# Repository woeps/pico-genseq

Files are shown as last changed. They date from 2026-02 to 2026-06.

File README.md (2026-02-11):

# GenSeq

A generative hardware MIDI sequencer based on the Raspberry Pi Pico (RP2040).

:warning: This project is still in development. It may take some (more) time to get to a stable state. :warning:

## Goal

GenSeq is a hardware MIDI sequencer that creates generative musical patterns based on separate sequences of pitches and rhythms. It provides real-time MIDI output with precise timing, an intuitive user interface, and extensible architecture for future enhancements.

## Key Features

- **Dual-core architecture** - Separates UI and sequencer logic for responsive performance
- **Generative sequencing** - Creates patterns using Euclidean rhythm algorithms
- **Real-time MIDI output** - Precise timing with MIDI clock support
- **Interactive UI** - LCD display, rotary encoder, and button matrix
- **Pattern management** - Multiple patterns with shared pitch/rhythm sets
- **Extensible design** - Clean architecture for easy feature additions

## Documentation

Online documentation is available at [https://woeps.github.io/pico-genseq/](https://woeps.github.io/pico-genseq/).

For comprehensive documentation, see the [docs/](docs/) directory:
- [Architecture Deep Dive](docs/architecture/architecture-deep-dive.md) - Technical details
- [Build & Flash Guide](docs/technical/build-flash.md) - Detailed instructions
- [Dependencies & Setup](docs/reference/dependencies.md) - Development environment
- [Troubleshooting](docs/reference/troubleshooting.md) - Common issues

## Building
- `mkdir build`
- `cd ./build`
- `cmake .. -G Ninja`
- `ninja clean` - optionally
- `ninja`

## Flashing
- either: copy `build/genseq.uf2` to the device
- or: use debugger ([PicoProbe](docs/technical/build-flash.md#method-2-picoprobe-flashing-advanced))

## Debugging
- in VSCode, press F5 / select `Pico Debug (Cortex-Debug)` in Run & Debug Toolbar

## Resources

- Midi Clock (tempo) analyzer: https://disasterarea.io/midiclock

## TODO

See [TODO.md](TODO.md) for detailed task list and implementation notes.

Key upcoming features:
- [ ] Manual step editing for rhythm sets
- [ ] UI configuration for settings (Euclidean pulses, length, etc.)
- [ ] Decouple MIDI from sequencer core
- [ ] Move step selection logic to play_mode.cpp

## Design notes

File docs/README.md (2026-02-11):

# GenSeq Documentation

Welcome to the GenSeq documentation. This section provides comprehensive guides for developing, building, and understanding the GenSeq MIDI sequencer project.

## Quick Start

- [Repository Structure](architecture/repository-structure.md) - Understand the project organization
- [Dependencies & Requirements](reference/dependencies.md) - Set up your development environment
- [Build & Flash](technical/build-flash.md) - Build and flash the firmware

## Core Documentation

### Architecture
- [Repository Structure](architecture/repository-structure.md) - Project layout and dual-core architecture
- [Architecture Deep Dive](architecture/architecture-deep-dive.md) - Technical details of the system design
- [Hardware Configuration](architecture/hardware-config.md) - Pin assignments and wiring diagrams

### Development
- [CMake Configuration](development/cmake-configuration.md) - Build system setup and common operations
- [Development Workflow](development/development-workflow.md) - Coding standards and best practices
- [UI System Guide](development/ui-system-guide.md) - User interface architecture and components

### Technical
- [MIDI Implementation](technical/midi-implementation.md) - MIDI output and timing details
- [Build & Flash Guide](technical/build-flash.md) - Build instructions and flashing procedures

### Reference
- [Dependencies & Requirements](reference/dependencies.md) - Software and hardware requirements
- [Troubleshooting FAQ](reference/troubleshooting.md) - Common issues and solutions

## Project Overview

GenSeq is a generative hardware MIDI sequencer based on the Raspberry Pi Pico (RP2040). It features:

- **Dual-core architecture** separating UI and sequencing
- **Real-time MIDI output** with precise timing
- **Generative patterns** using Euclidean rhythms
- **Extensible UI** with LCD display and LED matrix
- **Full MIDI implementation** including clock output

## Getting Started

1. **Set up environment** - Follow [Dependencies & Requirements](reference/dependencies.md)
2. **Build the project** - Use the [Build & Flash Guide](technical/build-flash.md)
3. **Understand the architecture** - Read [Repository Structure](architecture/repository-structure.md)
4. **Start developing** - Follow the [Development Workflow](development/development-workflow.md)

## Documentation Structure

```
docs/
├── README.md                    # This file
├── architecture/                # Architecture documentation
│   ├── repository-structure.md  # Project organization
│   ├── architecture-deep-dive.md # Technical architecture
│   └── hardware-config.md       # Hardware documentation
├── development/                 # Development guides
│   ├── cmake-configuration.md   # Build system details
│   ├── development-workflow.md  # Development guide
│   └── ui-system-guide.md       # UI architecture
├── technical/                   # Technical documentation
│   ├── build-flash.md          # Build and flash procedures
│   └── midi-implementation.md   # MIDI system details
└── reference/                   # Reference materials
    ├── dependencies.md          # Setup requirements
    └── troubleshooting.md      # Common issues
```

## Contributing to Documentation

When adding new features:
1. Update relevant documentation sections
2. Add new pages for major features
3. Update pin assignments in [Hardware Configuration](architecture/hardware-config.md)
4. Document new commands in [Architecture Deep Dive](architecture/architecture-deep-dive.md)

## Resources

- [Main Project README](../README.md)
- [Pico SDK Documentation](https://raspberrypi.github.io/pico-sdk-doxygen/)
- [RP2040 Datasheet](https://datasheets.raspberrypi.org/rp2040/rp2040-datasheet.pdf)
- [MIDI Specification](https://www.midi.org/specifications)

## Support

If you encounter issues:
1. Check the [Troubleshooting FAQ](reference/troubleshooting.md)
2. Search existing GitHub issues
3. Create a new issue with detailed information
4. Include debug output and hardware details

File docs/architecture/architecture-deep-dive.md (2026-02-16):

# Architecture Deep Dive

## Overview

The GenSeq architecture leverages the RP2040's dual-core design to create a responsive real-time MIDI sequencer. This deep dive explores the technical decisions, data structures, and communication patterns that make it possible.

## Dual-Core Architecture

### Core Responsibilities

```
┌─────────────────┐    Commands     ┌─────────────────┐
│   Core 0        │ ──────────────► │   Core 1        │
│                 │                 │                 │
│ • UI Input      │                 │ • Sequencing    │
│ • Display       │                 │ • MIDI Output   │
│ • LEDs          │                 │ • Timing        │
│ • User Logic    │                 │ • Pattern Mgmt  │
│                 │                 │                 │
└─────────────────┘                 └─────────────────┘
```

### Why Dual-Core?

1. **Real-time Constraints**: MIDI timing must be precise (±1ms)
2. **UI Responsiveness**: User interactions should never affect timing
3. **Separation of Concerns**: Clean architecture boundaries
4. **Future Expansion**: Room for additional features

### Core Synchronization

The cores communicate through:
- **Mailbox**: Fast inter-core messaging
- **Command Queue**: Asynchronous command processing
- **Shared Memory**: Read-only data structures

## Data Architecture

### Musical Data Separation

The sequencer separates musical data into three distinct types:

```
Pattern
├── Pitch Set      (What notes to play)
├── Rhythm Set     (When to play them)
└── Play Mode      (How to play them)
```

#### Pitch Set
```cpp
class PitchSet {
    std::vector<uint8_t> pitches;    // MIDI note numbers
    std::vector<uint8_t> velocities; // Note velocities
    bool active;                     // Enable/disable
};
```

- Contains note information (C4, G4, etc.)
- Independent of timing
- Can be reused across patterns

#### Rhythm Set (Gate Set)
```cpp
class GateSet {
    std::vector<bool> gates;         // On/off for each step
    std::vector<uint8_t> lengths;    // Gate length percentage
    uint8_t length;                  // Number of steps
    bool active;                     // Enable/disable
};
```

- Defines timing and rhythm
- Euclidean algorithm for generation
- Gate length controls note duration

#### Pattern
```cpp
class Pattern {
    PitchSet* pitchSet;              // Reference to pitch data
    GateSet* gateSet;                // Reference to rhythm data
    PlayMode playMode;               // Playback algorithm
    uint8_t currentStep;             // Current position
    bool active;                     // Play this pattern?
};
```

- Combines pitch and rhythm sets
- Multiple patterns can share sets
- Each pattern has independent state

### Play Modes

Different algorithms for note selection:

1. **Forward**: Linear progression through steps
2. **Random**: Random note selection
3. **Euclidean**: Evenly spaced notes
4. **Reverse**: Backward progression

## Command System

### Command Structure

```cpp
enum class CommandType {
    PLAY,
    STOP,
    SET_BPM,
    SET_PATTERN_ACTIVE,
    MODIFY_PITCH_SET,
    MODIFY_GATE_SET,
    // ... more commands
};

struct Command {
    CommandType type;
    uint8_t data[4];  // Command-specific data
};
```

### Command Flow

```
UI Core (Core 0)              Sequencer Core (Core 1)
     │                              │
     ├─> User presses PLAY ─────────► │
     │                              │
     ├─> Create Command             │
     │    type = PLAY               │
     │                              │
     ├─> Send via Mailbox ──────────►│
     │                              │
     │                         Process Command
     │                              │
     │                         Start Sequencer
     │                              │
     │                         Send MIDI Clock
```

### Command Processing

The sequencer processes commands in its main loop:
```cpp
void sequencerLoop() {
    while (true) {
        // Check for commands
        if (multicore_fifo_rvalid()) {
            Command cmd = multicore_fifo_pop_blocking();
            processCommand(cmd);
        }
        
        // Update sequencing
        if (shouldTick()) {
            processTick();
        }
        
        // Send MIDI
        sendPendingMIDI();
    }
}
```

## Timing System

### Tick-Based Sequencing

The sequencer uses a tick-based timing system:

- **PPQN**: Pulses Per Quarter Note (typically 24)
- **BPM**: Beats Per Minute (user configurable)
- **Tick Interval**: 60,000,000 / (BPM * PPQN * 1000) microseconds

### Timing Precision

```cpp
// Timer interrupt for precise timing
void timerCallback() {
    sequencerTick();
    clearAlarm();
    setAlarm(nextTickTime);
}
```

### MIDI Clock Generation

MIDI clock messages are sent at 24 PPQN:
```cpp
void sendMIDIClock() {
    sendMIDIMessage(0xF8); // MIDI Clock message
}
```

## UI Architecture

### Component Hierarchy

```
UIController
├── hardware/                (concrete types, no interfaces)
│   ├── HardwareConfig
│   ├── Button (×6, A-F)
│   ├── Encoder
│   ├── Led
│   └── LedMatrix
├── state/                   (state management)
│   ├── StateManager (singleton)
│   ├── Reducer (pure function + state-setters)
│   └── UIState
└── views/                   (render-only)
    └── MainView
```

### Data Flow

```
Button/Encoder → Event → StateManager → reduce(state, event) → new state → listener → View::render()
                                                                    ↓
                                                              commands::sendCommand() → Core 1
```

### Reducer Pattern

State transitions are handled by a pure reducer function. State-setter functions abstract away
mutating state fields and sending the corresponding commands:

```cpp
// State-setter functions: mutate state and send the corresponding command
void setBpm(UIState& state, int bpm);
void setPlaying(UIState& state, bool playing);

// All state logic in one place
UIState reduce(const UIState& state, const Event& event) {
    UIState newState = state;
    switch (event.type) {
        case EventType::ENCODER_CHANGED:
            setBpm(newState, state.bpm + event.data.encoder.delta);
            break;
        case EventType::BUTTON_PRESSED:
            setPlaying(newState, !state.playing);
            break;
    }
    return newState;
}
```

### View System

Views are render-only — they never mutate state:

```cpp
class IView {
public:
    virtual ~IView() = default;
    virtual void onEnter() {}
    virtual void onExit() {}
    virtual void render(const UIState& state) = 0;
};
```

## Memory Management

### Core-Specific Memory

Each core has its own stack:
```cpp
// Core 0 stack (UI)
#define UI_STACK_SIZE 0x1000

// Core 1 stack (Sequencer)
#define SEQUENCER_STACK_SIZE 0x2000
```

### Shared Memory

Read-only data can be shared:
```cpp
// Flash-stored data accessible by both cores
const uint8_t* sharedData = (const uint8_t*)0x10000000;
```

### Dynamic Allocation

Minimal dynamic allocation to avoid fragmentation:
- Pre-allocated buffers
- Fixed-size arrays
- Pool allocators for frequent allocations

## Interrupt Handling

### Core 0 Interrupts

- **GPIO**: Button and encoder inputs
- **I2C**: Display communication
- **Timer**: UI refresh timing

### Core 1 Interrupts

- **Timer**: Sequencer tick
- **UART**: MIDI transmission
- **DMA**: Efficient data transfer

### PIO Programs

Custom PIO programs for hardware:

```pio
// Encoder reading PIO
program encoder_reader {
    set pins, 0
    set x, 0
    
    label loop:
    in pins, 2
    mov x, isr
    jmp x != y, changed
    jmp loop
    
    label changed:
    mov y, x
    irq 0
    jmp loop
}
```

## Performance Considerations

### Critical Sections

MIDI output must be uninterrupted:
```cpp
// Disable interrupts during critical MIDI operations
uint32_t interrupt_state = save_and_disable_interrupts();
sendMIDIMessage(msg);
restore_interrupts(interrupt_state);
```

### DMA Usage

DMA for efficient data transfer:
```cpp
// DMA for LED matrix updates
dma_channel_configure(dma_chan,
    &dma_config,
    &led_data,          // Destination
    &led_buffer,        // Source
    LED_COUNT,          // Transfer count
    true                // Start immediately
);
```

### Optimization Strategies

1. **Minimize Inter-Core Communication**: Batch commands
2. **Use Lookup Tables**: For common calculations
3. **Avoid Floating Point**: Use fixed-point arithmetic
4. **Cache Frequently Used Data**: Keep in fast memory

## Debugging Architecture

### Core-Specific Debugging

Each core can be debugged independently:
```bash
# Debug Core 0 (UI)
openocd -f interface/cmsis-dap.cfg -f target/rp2040.cfg -c "bp main.0"

# Debug Core 1 (Sequencer)
openocd -f interface/cmsis-dap.cfg -f target/rp2040.cfg -c "bp main.1"
```

### Logging

Different logging levels for each core:
```cpp
// UI logging
printf("UI: Button pressed %d\n", buttonId);

// Sequencer logging
printf("SEQ: Pattern %d tick %d\n", patternId, tick);
```

## Future Architecture Considerations

### Scalability

The architecture supports:
- Additional patterns
- New play modes
- More UI views
- Extra hardware components

### Extensibility

Adding new features:
1. UI features: Add to Core 0
2. Sequencer features: Add to Core 1
3. New commands: Extend command enum
4. New hardware: Add to HAL

### Performance Headroom

Current utilization:
- Core 0: ~30% (UI is lightweight)
- Core 1: ~60% (Sequencing is intensive)
- Memory: ~50% of RAM available

## Summary

The GenSeq architecture successfully separates UI and sequencing concerns across two cores, enabling real-time MIDI performance while maintaining responsive user interaction. The clean data architecture and command system provide a solid foundation for future enhancements.

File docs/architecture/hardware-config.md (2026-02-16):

# Hardware Configuration

## Overview

The GenSeq hardware configuration defines all pin assignments, supported components, and wiring diagrams. This guide covers everything needed to connect the hardware components correctly.

## Pin Assignments

### Current Pin Configuration

```cpp
// From src/config/pins.h

// BUTTONS (A-F)
#define BUTTON_A_PIN 20
#define BUTTON_B_PIN 21
#define BUTTON_C_PIN 0  // TODO: assign actual pin
#define BUTTON_D_PIN 0  // TODO: assign actual pin
#define BUTTON_E_PIN 0  // TODO: assign actual pin
#define BUTTON_F_PIN 0  // TODO: assign actual pin

// ENCODER
#define ENCODER_PIN_A 14  // Encoder phase A
#define ENCODER_PIN_B 15  // Encoder phase B
#define ENCODER_PIO pio0  // PIO block 0
#define ENCODER_SM 0      // State machine 0

// MIDI UART
#define MIDI_UART uart1       // UART block 1
#define MIDI_UART_PIN_TX 8    // MIDI transmit pin
#define MIDI_UART_PIN_RX 9    // MIDI receive pin

// POTENTIOMETER (ADC)
#define POT_PIN 26            // 10kΩ linear pot on ADC0

// STATUS LED
#define LED_PIN 25            // Onboard LED
```

### Pin Map Diagram

```
Raspberry Pi Pico Pinout
========================

          3V3  (40) [ ] (39)  GND
          GPIO2 (35) [ ] (38)  GPIO3
          GPIO4 (34) [ ] (37)  GPIO5  ← I2C SCL (Display)
          GPIO6 (33) [ ] (36)  GPIO7
          GPIO8 (32) [ ] (31)  GPIO9  ← MIDI RX
  MIDI TX → GPIO10(31) [ ] (30)  GPIO11
          GPIO12(30) [ ] (29)  GPIO13
 Encoder A → GPIO14(29) [ ] (28)  GPIO13 ← Encoder B
          GPIO16(27) [ ] (27)  GPIO17
          GPIO18(26) [ ] (26)  GPIO19
Button E → GPIO20(25) [ ] (25)  GPIO21 ← Button A
          GPIO22(24) [ ] (24)  GPIO23
          GND   (23) [ ] (23)  VSYS
          VBUS  (22) [ ] (22)  GND
          3V3   (21) [ ] (21)  3V3
          LED   (20) [ ] (20)  GND
```

## Hardware Components

### 1. LCD Display

**Specification**: HD44780 with FC113 I2C controller

**Connection**:
```
Pico      →  Display Module
GPIO4     →  SDA
GPIO5     →  SCL
3V3       →  VCC
GND       →  GND
```

**I2C Address**: 0x27 (configurable via jumpers)

**Library**: Custom driver in `src/ui/hardware/driver/LCD_I2C.cpp`

### 2. Rotary Encoder

**Specification**: Quadrature encoder with push button

**Connection**:
```
Pico      →  Encoder
GPIO14    →  Phase A
GPIO15    →  Phase B
GPIO20    →  Button
3V3       →  VCC
GND       →  GND
```

**Implementation**: PIO-based for interrupt-free reading

### 3. MIDI Interface

**Specification**: 5-pin DIN MIDI connector

**Circuit**:
```
Pico TX → 220Ω → MIDI Pin 5
MIDI Pin 4 → 220Ω → Pico RX
MIDI Pin 2 → GND
```

**Isolation**: Opto-isolator recommended for MIDI input

### 4. Button Matrix

**Specification**: 16 buttons in 8x2 matrix

**Connection Pattern**:
```
Rows: GPIO22, GPIO21, GPIO20, GPIO19
Cols: GPIO18, GPIO17, GPIO16, GPIO15
```

**Scanning**: Row-by-row scanning with debouncing

### 5. Potentiometer

**Specification**: 10kΩ linear potentiometer

**Connection**:
```
Pico      →  Potentiometer
GPIO26    →  Wiper (middle pin) via RC low-pass filter
3V3       →  One outer pin
GND       →  Other outer pin
```

**RC Low-Pass Filter**:
```
POT_WIPER ─── 1kΩ ─── GPIO26 (ADC0)
                  │
                100nF
                  │
                 GND
```
- **R**: 1kΩ, **C**: 100nF (cutoff ≈ 1.6 kHz)
- Filters high-frequency noise while preserving responsiveness for manual control

**ADC**: 12-bit (0–4095), read via `hardware_adc`

**Noise Filtering**: RC low-pass filter on input + EMA software smoothing (α=1/4) + threshold-based change detection (±4 LSBs)

### 6. LED Matrix

**Specification**: 16x2 WS2812B LED strip

**Connection**:
```
Pico GPIO23 → LED Data In
5V          → LED VCC
GND         → LED GND
```

**Driver**: DMA-based for smooth updates

## Wiring Diagram

### Complete Wiring

```
┌─────────────────────────────────────────────────────┐
│                   PICO BOARD                        │
│                                                     │
│    [USB]                                           │
│                                                     │
│  GPIO4 ────────┐                                   │
│  GPIO5 ────────┼───[ I2C LCD ]                     │
│  3V3 ─────────┘                                   │
│  GND ─────────────────────────────────────────────┐ │
│                                                   │ │
│  GPIO14 ──────┐                                   │ │
│  GPIO15 ──────┼───[ ENCODER ]                     │ │
│  GPIO20 ──────┘                                   │ │
│                                                   │ │
│  GPIO8 ───┐                                        │ │
│  GPIO9 ───┼───[ MIDI CIRCUIT ]                     │ │
│  GND ─────┘                                        │ │
│                                                   │ │
│  GPIO23 ─────────[ LED STRIP ]────────────────────┘ │
│                                                     │
│  [OTHER GPIO] ────[ BUTTON MATRIX ]                │
│                                                     │
└─────────────────────────────────────────────────────┘
```

## Adding New Hardware

### 1. Define Pins

Add to `src/config/pins.h`:
```cpp
// New hardware pins
#define NEW_DEVICE_PIN 26
#define NEW_DEVICE_IRQ_PIN 27
```

### 2. Create Driver

Create files in `src/ui/hardware/driver/`:
```cpp
// new_device.h
class NewDevice {
public:
    NewDevice(uint8_t pin);
    void init();
    void update();
    int read();
private:
    uint8_t _pin;
};
```

### 3. Update CMakeLists.txt

Add to CMakeLists.txt if needed:
```cmake
target_link_libraries(genseq
    # ... existing libraries ...
    hardware_spi  # If using SPI
)
```

### 4. Integrate with UI

Add to UI controller:
```cpp
// In ui.cpp
NewDevice newDevice(NEW_DEVICE_PIN);

void updateUI() {
    newDevice.update();
    // ... other updates
}
```

## PIO Programs

### Encoder Reader PIO

Located at `src/ui/hardware/driver/encoder.pio`:

```pio
.program encoder_reader
.side_set 1 opt

; Read encoder state change
loop:
    in pins, 2        ; Read both encoder pins
    mov x, isr        ; Save to X
    jmp x != y, changed ; Check if changed
    jmp loop          ; No change, continue
    
changed:
    mov y, x          ; Save new state
    irq 0             ; Signal change
    jmp loop          ; Continue
```

### WS2812 LED PIO

Generated from `src/ui/hardware/driver/ws2812.pio`:
- Handles timing-critical LED data
- Uses DMA for efficient transfers
- Supports RGB color format

## Hardware Abstraction Layer

### Interfaces

All hardware implements standard interfaces:

```cpp
// Input devices
class IInput {
public:
    virtual void update() = 0;
    virtual bool hasChanged() = 0;
    virtual int getValue() = 0;
};

// Output devices
class IOutput {
public:
    virtual void update() = 0;
    virtual void setValue(int value) = 0;
};
```

### Hardware Configuration

Configuration in `src/ui/hardware/driver/HardwareConfig.h`:
```cpp
struct HardwareConfig {
    // Display settings
    static const uint8_t DISPLAY_WIDTH = 16;
    static const uint8_t DISPLAY_HEIGHT = 2;
    
    // LED settings
    static const uint16_t LED_COUNT = 32;
    static const uint8_t LED_BRIGHTNESS = 128;
    
    // Debounce settings
    static const uint8_t DEBOUNCE_MS = 50;
};
```

## Power Considerations

### Power Requirements

- **Pico Board**: 40mA @ 5V
- **LCD Display**: 20mA @ 5V
- **LED Strip**: 60mA per LED @ 5V (full brightness white)
- **MIDI Interface**: 5mA @ 5V
- **Total**: ~2A @ 5V with all LEDs at full brightness

### Power Supply Recommendations

1. **USB Power**: Sufficient for development (500mA)
2. **External Supply**: Required for full LED usage
3. **Decoupling**: 100µF capacitor near LED strip
4. **Protection**: 500mA polyfuse on 5V line

## Signal Integrity

### I2C Considerations

- Pull-up resistors: 4.7kΩ on SDA/SCL
- Cable length: < 1m recommended
- Speed: 100kHz (standard mode)

### MIDI Considerations

- Isolation: Opto-isolator on input
- Termination: Not required for short cables
- Cable length: Up to 15m with proper shielding

### GPIO Considerations

- 3.3V logic levels
- Input protection: Series resistors for external signals
- Output current: Max 16mA per pin

### ADC Considerations

- RC low-pass filter (1kΩ + 100nF) on potentiometer input to reduce high-frequency noise
- Cutoff frequency: ~1.6 kHz
- Source impedance kept below RP2040 recommended maximum (~100kΩ)

## Troubleshooting Hardware

### Common Issues

1. **Display not working**:
   - Check I2C address (use I2C scanner)
   - Verify pull-up resistors
   - Check wiring connections

2. **Encoder jitter**:
   - Add hardware debouncing (0.1µF capacitor)
   - Increase software debounce time
   - Check for noise sources

3. **MIDI not sending**:
   - Verify MIDI wiring
   - Check baud rate (31250)
   - Test with MIDI monitor

4. **LED flickering**:
   - Check power supply
   - Verify ground connection
   - Reduce brightness

### Testing Procedures

1. **Continuity Test**: Verify all connections
2. **Voltage Test**: Check power at each component
3. **Signal Test**: Use logic analyzer for timing
4. **Isolation Test**: Test components individually

## Future Hardware Expansion

### Planned Additions

1. **Storage**: SD card for pattern storage
2. **Connectivity**: USB MIDI host mode
3. **Expansion**: More buttons and LEDs
4. **Sensors**: CV inputs for modulation

### Pin Availability

Free pins for expansion:
- GPIO26, GPIO27, GPIO28, GPIO29
- ADC pins available for analog input

## Summary

The hardware configuration is designed for:
- Clean signal routing
- Proper power distribution
- Easy expansion
- Reliable operation

All pin assignments are documented and easily modifiable in the source code. The hardware abstraction layer makes it simple to add new components or modify existing ones.

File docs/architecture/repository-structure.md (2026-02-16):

# Repository Structure

## Overview

The GenSeq project follows a well-organized structure that separates concerns between the user interface and sequencer logic, leveraging the dual-core architecture of the Raspberry Pi Pico (RP2040).

```
genseq/
├── src/                    # All source code
│   ├── sequencer/         # Core sequencing logic (runs on core 1)
│   ├── ui/                # User interface components (runs on core 0)
│   ├── commands/          # Inter-core communication
│   ├── config/            # Pin assignments & hardware config
│   ├── generated/         # Auto-generated PIO headers
│   └── genseq.cpp         # Main entry point
├── docs/                  # Documentation
├── build/                 # Build output directory
├── case/                  # Hardware case designs
├── data/                  # Datasheet & Spec files
├── .vscode/               # VSCode configuration
├── .clangd                # clangd configuration
├── CMakeLists.txt         # CMake build configuration
├── pico_sdk_import.cmake  # Pico SDK import
└── README.md              # Project overview
```

## Architecture Philosophy

### Dual-Core Separation

The project strategically uses both cores of the RP2040:

- **Core 0**: User Interface (UI)
  - Handles all user input (buttons, encoders)
  - Manages display updates
  - Sends commands to sequencer
  - Responsive to user interactions
  
- **Core 1**: Sequencer Logic
  - Real-time MIDI sequencing
  - Pattern management
  - Timing-critical operations
  - Uninterrupted MIDI output

### Benefits of This Architecture

1. **Real-time Performance**: MIDI timing is never affected by UI operations
2. **Responsiveness**: UI remains smooth even during complex sequencing
3. **Modularity**: Clear separation allows independent development
4. **Scalability**: Easy to add new UI features without affecting timing
5. **Debugging**: Issues can be isolated to specific cores

### Potential Pitfalls

1. **Communication Overhead**: Inter-core communication adds latency
2. **Synchronization**: Must avoid race conditions when sharing data
3. **Memory Management**: Each core has its own stack, careful with shared memory
4. **Debugging Complexity**: Core-specific issues can be harder to trace

## Directory Deep Dive

### `/src/sequencer/`

The heart of the sequencing engine:

- `sequencer.h/cpp` - Main sequencer controller
- `pattern.h/cpp` - Pattern management and playback
- `gate_set.h/cpp` - Rhythm/gate timing data
- `pitch_set.h/cpp` - Note pitch data
- `velocity_set.h/cpp` - Note velocity data
- `midi_messages.h` - MIDI message definitions

### `/src/ui/`

User interface subsystem:

```
ui/
├── state/               # State management
│   ├── UIState.h        # State structure
│   ├── Reducer.h/cpp    # Pure reducer + state-setter functions
│   └── StateManager.h/cpp # Holds state, dispatches to reducer, notifies listeners
├── views/               # View system
│   ├── IView.h          # Render-only view interface
│   └── MainView.h/cpp   # Main view implementation
├── hardware/            # Hardware components
│   ├── driver/          # Low-level drivers (LCD, PIO, WS2812)
│   ├── HardwareConfig.h # Pin/peripheral configuration struct
│   ├── Button.h/cpp     # Button with debounce + hold detection
│   ├── Encoder.h/cpp    # Rotary encoder via PIO
│   ├── Led.h/cpp        # LED with blink support
│   └── LedMatrix.h/cpp  # 16x16 WS2812 LED matrix via DMA
├── ui.h/cpp             # UI facade and main loop
├── UIController.h/cpp   # Orchestrator: creates hardware + views
├── Event.h              # Union-based event definitions
└── Types.h              # Shared enums (ButtonId)
```

- `ui.h/cpp` - UI facade (entry point from main)
- `state/` - State management: reducer, state-setter functions, state manager
- `views/` - Render-only views driven by state changes
- `hardware/` - Concrete hardware components (no abstract interfaces)

### `/src/commands/`

Inter-core communication:

- `command.h/cpp` - Command message definitions
- Enables UI to send instructions to sequencer

### `/src/generated/`

Auto-generated files:

- PIO program headers (e.g., `ws2812.pio.h`)
- Generated at build time from `.pio` files

## Key Architectural Patterns

### 1. Command Pattern

The UI sends commands to the sequencer:
```cpp
// Example command flow
UI Core --[Play Command]--> Sequencer Core
```

### 2. Data Separation

Musical data is separated into:
- **Pitch Sets**: Note pitches and velocities
- **Rhythm Sets**: Timing and gate information
- **Patterns**: Combinations of pitch and rhythm sets

### 3. Event-Driven Reducer Pattern

UI uses a unidirectional data flow:
- Hardware emits `Event` structs to `StateManager`
- `StateManager` calls the pure `reduce()` function
- State changes notify views via listener callback
- Views only render — they never mutate state

## Development Considerations

### Adding New Features

1. **UI Features**: Add to `/src/ui/` namespace
2. **Sequencer Features**: Add to `/src/sequencer/` namespace
3. **New Commands**: Define in `/src/commands/`
4. **Hardware Support**: Add to `/src/ui/hardware/`

### Best Practices

1. Keep core-specific code isolated
2. Use commands for cross-core communication
3. Avoid shared mutable state between cores
4. Test timing-critical code on the sequencer core
5. Keep UI responsive, avoid blocking operations

### File Organization Guidelines

- Header files (`.h`) should contain interfaces and declarations
- Implementation files (`.cpp`) contain actual logic
- Keep related functionality in the same directory
- Use forward declarations to minimize include dependencies

## Build Artifacts

The build process creates:
- `genseq.uf2` - UF2 file for USB flashing
- `genseq.elf` - ELF binary for debugging
- `compile_commands.json` - For clangd language server
- Various `.bin` and `.hex` files

## Summary

This repository structure supports a clean, maintainable codebase that leverages the RP2040's dual-core architecture effectively. The separation of UI and sequencing concerns ensures real-time performance while maintaining code organization and extensibility.

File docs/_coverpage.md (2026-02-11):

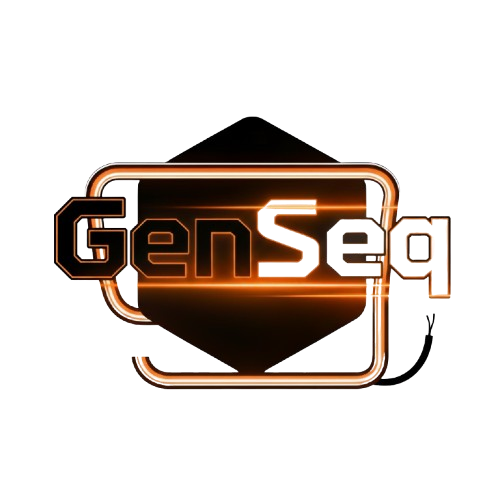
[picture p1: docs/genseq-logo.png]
GenSeq


> Generative Midi Sequencer

[GitHub](https://github.com/woeps/pico-genseq)
[Docs](https://woeps.github.io/pico-genseq)

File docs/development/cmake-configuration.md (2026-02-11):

# CMake Configuration

## Overview

The GenSeq project uses CMake with the Raspberry Pi Pico SDK to build the firmware. The `CMakeLists.txt` file is configured to handle the dual-core architecture, PIO programs, and all necessary hardware libraries.

## CMakeLists.txt Breakdown

### Basic Configuration

```cmake
cmake_minimum_required(VERSION 3.13)

set(CMAKE_C_STANDARD 11)
set(CMAKE_CXX_STANDARD 17)
set(CMAKE_EXPORT_COMPILE_COMMANDS ON)
```

- **C Standard**: C11 for C files
- **C++ Standard**: C++17 for C++ files
- **Compile Commands**: Generates `compile_commands.json` for clangd

### Pico SDK Integration

```cmake
# == DO NOT EDIT THE FOLLOWING LINES for the Raspberry Pi Pico VS Code Extension to work ==
if(WIN32)
    set(USERHOME $ENV{USERPROFILE})
else()
    set(USERHOME $ENV{HOME})
endif()
set(sdkVersion 2.1.1)
set(toolchainVersion 14_2_Rel1)
set(picotoolVersion 2.1.1)
set(picoVscode ${USERHOME}/.pico-sdk/cmake/pico-vscode.cmake)
if (EXISTS ${picoVscode})
    include(${picoVscode})
endif()
# ====================================================================================
```

This section:
- Detects the operating system
- Sets SDK and toolchain versions
- Includes the VSCode extension helper if present
- **Important**: Do not modify these lines if using the Pico VSCode extension

### Project Setup

```cmake
set(PICO_BOARD pico CACHE STRING "Board type")

# Pull in Raspberry Pi Pico SDK (must be before project)
include(pico_sdk_import.cmake)

project(genseq C CXX ASM)

# Initialise the Raspberry Pi Pico SDK
pico_sdk_init()
```

- Sets target board to `pico` (can be changed to `pico2` etc.)
- Includes the Pico SDK import
- Defines the project with C, C++, and Assembly support
- Initializes the SDK

### Source File Management

```cmake
# Find all source files in the sequencer, commands, and UI directories
file(GLOB_RECURSE SEQUENCER_SOURCES "${CMAKE_CURRENT_SOURCE_DIR}/src/sequencer/*.cpp")
file(GLOB_RECURSE COMMANDS_SOURCES "${CMAKE_CURRENT_SOURCE_DIR}/src/commands/*.cpp")
file(GLOB_RECURSE UI_SOURCES "${CMAKE_CURRENT_SOURCE_DIR}/src/ui/*.cpp" "${CMAKE_CURRENT_SOURCE_DIR}/src/ui/*.c")

# Print the found source files for debugging
message(STATUS "Sequencer sources: ${SEQUENCER_SOURCES}")
message(STATUS "Commands sources: ${COMMANDS_SOURCES}")
message(STATUS "UI sources: ${UI_SOURCES}")
```

This approach:
- Automatically finds all source files in each directory
- Supports both `.cpp` and `.c` files for UI
- Provides debug output showing found files

### Executable Definition

```cmake
# Add source files for the sequencer, commands, and UI components
add_executable(genseq 
    src/genseq.cpp
    ${SEQUENCER_SOURCES}
    ${COMMANDS_SOURCES}
    ${UI_SOURCES}
)
```

### PIO Program Generation

```cmake
file(MAKE_DIRECTORY ${CMAKE_CURRENT_LIST_DIR}/src/generated)
pico_generate_pio_header(genseq ${CMAKE_CURRENT_LIST_DIR}/src/ui/hardware/driver/ws2812.pio OUTPUT_DIR ${CMAKE_CURRENT_LIST_DIR}/src/generated)
```

- Creates the `src/generated` directory
- Generates C header from PIO assembly file
- Outputs to `src/generated` for inclusion

### Binary Metadata

```cmake
# binary info (readabl by picotool)
pico_set_program_name(genseq "GenSeq")
pico_set_program_version(genseq "0.1")
pico_set_program_description(genseq "Generative MIDI Sequence")
pico_set_program_url(genseq "https://github.com/woeps/pico-genseq")
```

Sets program information readable by `picotool`.

### Standard I/O Configuration

```cmake
# Modify the below lines to enable/disable output over UART/USB
pico_enable_stdio_uart(genseq 1)
pico_enable_stdio_usb(genseq 0)
```

- UART enabled for debug output
- USB stdio disabled (can be enabled for USB serial)

### Library Linking

```cmake
# Add the standard library to the build
target_link_libraries(genseq
    pico_stdlib
    pico_multicore
    hardware_pio
    hardware_uart
    hardware_gpio
    hardware_i2c
    hardware_dma
)
```

Links necessary Pico SDK libraries:
- `pico_stdlib` - Standard library includes
- `pico_multicore` - Dual-core support
- `hardware_pio` - PIO program support
- `hardware_uart` - UART communication (MIDI)
- `hardware_gpio` - GPIO control
- `hardware_i2c` - I2C for display
- `hardware_dma` - DMA for efficient data transfer

### Include Directories

```cmake
# Add the standard include files to the build
target_include_directories(genseq PRIVATE
        ${CMAKE_CURRENT_LIST_DIR}/src
        ${CMAKE_CURRENT_LIST_DIR}/src/generated
)
```

Adds source directories to the include path.

### Build Outputs

```cmake
pico_add_extra_outputs(genseq)
```

Generates additional build artifacts (UF2 file, etc.).

## Common Operations

### Adding a New Driver

1. Create source files in appropriate directory:
   ```
   src/ui/hardware/driver/new_driver.h
   src/ui/hardware/driver/new_driver.cpp
   ```

2. The `GLOB_RECURSE` will automatically pick up the new files

3. If the driver requires additional libraries:
   ```cmake
   target_link_libraries(genseq
       # ... existing libraries ...
       hardware_spi  # Add new library
   )
   ```

### Adding a New Library

1. Create library directory:
   ```
   src/libraries/new_lib/
   ├── new_lib.h
   └── new_lib.cpp
   ```

2. Add to CMakeLists.txt:
   ```cmake
   file(GLOB_RECURSE NEW_LIB_SOURCES "${CMAKE_CURRENT_SOURCE_DIR}/src/libraries/new_lib/*.cpp")
   
   add_executable(genseq 
       # ... existing sources ...
       ${NEW_LIB_SOURCES}
   )
   ```

### Adding a New PIO Program

1. Create `.pio` file:
   ```
   src/ui/hardware/driver/new_program.pio
   ```

2. Add header generation:
   ```cmake
   pico_generate_pio_header(genseq 
       ${CMAKE_CURRENT_LIST_DIR}/src/ui/hardware/driver/new_program.pio 
       OUTPUT_DIR ${CMAKE_CURRENT_LIST_DIR}/src/generated
   )
   ```

3. Include in code:
   ```cpp
   #include "new_program.pio.h"
   ```

### Conditional Compilation

To add build options:

```cmake
option(ENABLE_FEATURE "Enable new feature" OFF)

if(ENABLE_FEATURE)
    target_compile_definitions(genseq PRIVATE ENABLE_FEATURE=1)
    # Add additional sources or libraries
endif()
```

### Platform-Specific Code

```cmake
if(PICO_BOARD STREQUAL "pico2")
    target_compile_definitions(genseq PRIVATE PICO_BOARD=2)
    # Add Pico 2 specific code
endif()
```

## Build Types

### Debug Build

```bash
cd build
cmake -DCMAKE_BUILD_TYPE=Debug ..
ninja
```

Includes debug symbols and disables optimizations.

### Release Build

```bash
cd build
cmake -DCMAKE_BUILD_TYPE=Release ..
ninja
```

Optimized for size and speed.

## Build System Internals

### Compilation Database

The `CMAKE_EXPORT_COMPILE_COMMANDS ON` setting generates `compile_commands.json` which:
- Provides compile commands to clangd
- Enables proper code completion and error checking
- Is essential for the Windsurf IDE integration

### Ninja Build System

The project uses Ninja (specified in `.vscode/settings.json`):
- Faster builds than make
- Parallel compilation
- Better dependency tracking

## Troubleshooting

### Common CMake Issues

1. **SDK not found**:
   - Ensure `PICO_SDK_PATH` environment variable is set
   - Check SDK installation in `~/.pico-sdk/sdk/`

2. **Toolchain not found**:
   - Verify `PICO_TOOLCHAIN_PATH` is set
   - Check toolchain installation in `~/.pico-sdk/toolchain/`

3. **Missing sources**:
   - Check `message(STATUS)` output in build log
   - Verify file paths and extensions

### Clean Build

```bash
cd build
rm -rf *
cmake ..
ninja
```

### Verbose Build

```bash
ninja -v
```

Shows all compiler commands.

## Best Practices

1. **Use GLOB_RECURSE sparingly**: While convenient, it can hide missing files
2. **Keep CMake organized**: Group related configurations
3. **Document custom options**: Comment any project-specific CMake code
4. **Test clean builds**: Regularly build from scratch
5. **Version control CMakeLists.txt**: Track all build configuration changes

## Summary

The CMake configuration is designed to:
- Automatically handle source file discovery
- Support the dual-core architecture
- Integrate with the Pico SDK ecosystem
- Provide a smooth development experience with proper tooling support

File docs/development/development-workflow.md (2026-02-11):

# Development Workflow

## Overview

This guide outlines the recommended development workflow for the GenSeq project, including environment setup, coding practices, debugging procedures, and contribution guidelines.

## Initial Setup

### 1. Repository Setup

```bash
# Clone the repository
git clone https://github.com/woeps/pico-genseq.git
cd pico-genseq

# Create your feature branch
git checkout -b feature/your-feature-name

# Initialize submodules if any
git submodule update --init --recursive
```

### 2. Development Environment

#### VSCode Setup

1. Install required extensions:
   - Raspberry Pi Pico
   - C/C++ clangd
   - Cortex-Debug

2. Open the project:
   ```bash
   code .
   ```

3. Verify clangd is working:
   - Open a `.cpp` file
   - Check for code completion
   - Look for clangd status in status bar

#### Terminal Setup

```bash
# Add Pico SDK to PATH (add to ~/.bashrc)
export PICO_SDK_PATH=$HOME/.pico-sdk/sdk/2.1.1
export PICO_TOOLCHAIN_PATH=$HOME/.pico-sdk/toolchain/14_2_Rel1
export PATH=$PATH:$PICO_TOOLCHAIN_PATH/bin:$HOME/.pico-sdk/ninja/v1.12.1
```

### 3. First Build

```bash
# Create build directory
mkdir -p build
cd build

# Configure
cmake ..

# Build
ninja

# Should complete without errors
```

## Daily Development Workflow

### 1. Start of Day

```bash
# Pull latest changes
git checkout main
git pull origin main

# Update your branch
git checkout feature/your-feature
git rebase main

# Clean build
cd build
rm -rf *
cmake ..
ninja
```

### 2. Making Changes

#### Code Organization

Follow the directory structure:
```
src/
├── sequencer/     # Sequencer logic (Core 1)
├── ui/           # UI logic (Core 0)
├── commands/     # Inter-core communication
└── genseq.cpp    # Main entry point
```

#### Adding New Features

1. **UI Feature**:
   ```cpp
   // src/ui/views/NewView.h
   class NewView : public IView {
   public:
       void render() override;
       void handleInput(InputEvent event) override;
   };
   ```

2. **Sequencer Feature**:
   ```cpp
   // src/sequencer/new_feature.h
   namespace sequencer {
       class NewFeature {
       public:
           void update();
           bool isActive();
       };
   }
   ```

3. **New Command**:
   ```cpp
   // src/commands/command.h
   enum class CommandType {
       // ... existing commands
       NEW_FEATURE_TOGGLE,
   };
   ```

### 3. Build and Test

#### Incremental Build

```bash
# In build directory
ninja  # Only rebuilds changed files
```

#### Flash and Test

```bash
# Method 1: USB (quick testing)
cp genseq.uf2 /media/$(whoami)/RPI-RP2/

# Method 2: PicoProbe (development)
# Press F5 in VSCode
```

#### Test Procedure

1. **Unit Testing**:
   ```cpp
   // Simple test in main()
   #ifdef DEBUG
   testPitchSet();
   testGateSet();
   #endif
   ```

2. **Integration Testing**:
   - Test UI interaction
   - Verify MIDI output
   - Check timing accuracy

3. **Hardware Testing**:
   - Verify all buttons work
   - Check display updates
   - Test encoder response

### 4. Debugging

#### Serial Output

```cpp
// Enable debug output
printf("DEBUG: Pattern %d activated\n", patternId);

// Conditional debug
#ifdef DEBUG
printf("Sequencer tick: %d\n", tickCount);
#endif
```

#### Hardware Debugging

1. **PicoProbe Setup**:
   - Connect PicoProbe
   - Use VSCode debug configuration
   - Set breakpoints

2. **Common Debug Points**:
   ```cpp
   // In sequencer.cpp
   void sequencerTick() {
       // Break here to check timing
       if (shouldSendMIDI()) {
           sendMIDIMessage();
       }
   }
   
   // In ui.cpp
   void handleButtonPress() {
       // Break here to check input
       processButton(buttonId);
   }
   ```

#### Logic Analyzer

For timing-critical debugging:
- Monitor UART for MIDI
- Check I2C for display
- Verify GPIO timing

## Coding Standards

### 1. Code Style

#### C++ Guidelines

```cpp
// Naming conventions
class ClassName {          // PascalCase
public:
    void methodName();     // camelCase
private:
    int memberVariable;    // camelCase with underscore
    static const int CONSTANT_VALUE; // UPPER_SNAKE_CASE
};

// File organization
// header.h
#pragma once

#include <vector>

namespace sequencer {  // Use namespaces
    class MyClass {
        // Class definition
    };
}
```

#### C Guidelines

```c
// For C files (PIO drivers, etc.)
// snake_case for functions
#define CONSTANT_NAME "value"

struct struct_name {
    int member_name;
};

void function_name(struct struct_name* s);
```

### 2. Documentation

#### Header Documentation

```cpp
/**
 * @brief Manages MIDI pattern playback
 * 
 * The Pattern class combines pitch and rhythm sets to create
 * playable musical patterns. Multiple patterns can run
 * simultaneously.
 */
class Pattern {
public:
    /**
     * @brief Create a new pattern
     * @param pitchSet Pointer to pitch data
     * @param gateSet Pointer to rhythm data
     */
    Pattern(PitchSet* pitchSet, GateSet* gateSet);
};
```

#### Inline Documentation

```cpp
// Update the sequencer state
// This must be called every 24 PPQN ticks
void sequencer::update() {
    // Check for new commands from UI
    if (hasPendingCommands()) {
        processCommands();
    }
    
    // Advance pattern position
    currentStep = (currentStep + 1) % patternLength;
}
```

### 3. Error Handling

```cpp
// Use assertions for debugging
#include <cassert>

void setPatternLength(uint8_t length) {
    assert(length > 0 && length <= MAX_PATTERN_LENGTH);
    patternLength = length;
}

// Return error codes
enum class ErrorCode {
    SUCCESS,
    INVALID_PATTERN,
    MEMORY_ERROR,
};

ErrorCode loadPattern(uint8_t id) {
    if (id >= MAX_PATTERNS) {
        return ErrorCode::INVALID_PATTERN;
    }
    // ... load pattern
    return ErrorCode::SUCCESS;
}
```

## Git Workflow

### 1. Branch Strategy

```
main                 ← Production-ready code
├── develop          ← Integration branch
├── feature/ui-redesign
├── feature/euclidean-rhythm
└── hotfix/midi-timing
```

### 2. Commit Guidelines

#### Commit Message Format

```
type(scope): brief description

Detailed explanation if needed.

Closes #123
```

Types:
- `feat`: New feature
- `fix`: Bug fix
- `docs`: Documentation
- `style`: Code style
- `refactor`: Refactoring
- `test`: Testing
- `chore`: Maintenance

#### Examples

```
feat(sequencer): add euclidean rhythm generator

Implements Bjorklund's algorithm for generating
euclidean rhythm patterns. Users can set number
of pulses and total steps.

Closes #45

fix(ui): correct encoder direction

Encoder was reading backwards due to swapped
phase A and B pins in hardware config.
```

### 3. Pull Request Process

1. **Create PR**:
   - Push feature branch
   - Create pull request on GitHub
   - Request review from maintainer

2. **PR Checklist**:
   - [ ] Code builds without warnings
   - [ ] All tests pass
   - [ ] Documentation updated
   - [ ] Hardware tested
   - [ ] No regressions

3. **Review Process**:
   - Address reviewer comments
   - Update code as needed
   - Maintain clean commit history

## Testing Strategy

### 1. Unit Testing

```cpp
// Simple test framework
#define TEST_ASSERT(condition) \
    do { \
        if (!(condition)) { \
            printf("FAIL: %s:%d\n", __FILE__, __LINE__); \
            return false; \
        } \
    } while(0)

bool testPitchSet() {
    PitchSet ps;
    ps.addNote(60, 127);  // C4, max velocity
    TEST_ASSERT(ps.getNoteCount() == 1);
    TEST_ASSERT(ps.getNote(0) == 60);
    return true;
}
```

### 2. Integration Testing

```cpp
// Test inter-core communication
void testCommandSystem() {
    // Send command from UI core
    Command cmd = {CommandType::PLAY, 0};
    multicore_fifo_push_blocking(cmd.raw);
    
    // Check if sequencer receives
    sleep_ms(10);
    TEST_ASSERT(sequencer.isPlaying());
}
```

### 3. Hardware Testing

Create test hardware setup:
- Test all button combinations
- Verify display characters
- Check MIDI output with monitor

## Performance Optimization

### 1. Profiling

```cpp
// Simple timing measurement
uint32_t start = time_us_32();
functionToProfile();
uint32_t duration = time_us_32() - start;
printf("Function took %d microseconds\n", duration);
```

### 2. Optimization Targets

- **MIDI Timing**: Must be < 1ms jitter
- **UI Response**: < 50ms latency
- **Memory Usage**: < 128KB RAM
- **CPU Usage**: < 80% per core

### 3. Common Optimizations

```cpp
// Use fixed-point instead of float
#define FIXED_POINT_SCALE 1000
int32_t bpmFixed = 120 * FIXED_POINT_SCALE;

// Use lookup tables
static const uint16_t sineTable[256] = { ... };

// Minimize inter-core communication
batchCommands();
```

## Release Process

### 1. Version Bumping

Update version in:
- `CMakeLists.txt`
- `README.md`
- Create git tag

### 2. Release Build

```bash
# Clean release build
rm -rf build
mkdir build
cd build
cmake -DCMAKE_BUILD_TYPE=Release ..
ninja

# Create release package
tar -czf genseq-v1.0.0.tar.gz genseq.uf2 README.md
```

### 3. Documentation

- Update changelog
- Review documentation
- Create release notes

## Troubleshooting

### Common Development Issues

1. **Build Fails**:
   ```bash
   # Clean and rebuild
   rm -rf build
   mkdir build && cd build
   cmake .. && ninja
   ```

2. **clangd Not Working**:
   - Check `.clangd` file
   - Verify `compile_commands.json`
   - Restart VSCode

3. **Debug Not Connecting**:
   - Check PicoProbe wiring
   - Verify OpenOCD version
   - Try external OpenOCD

4. **Hardware Not Responding**:
   - Check power supply
   - Verify pin assignments
   - Test with multimeter

## Best Practices Summary

1. **Code Organization**: Keep core-specific code separate
2. **Testing**: Test early and often
3. **Documentation**: Document as you code
4. **Version Control**: Clean commit history
5. **Performance**: Profile before optimizing
6. **Hardware**: Protect against static discharge
7. **Collaboration**: Review code before merging

## Resources

- [Pico SDK Documentation](https://raspberrypi.github.io/pico-sdk-doxygen/)
- [RP2040 Datasheet](https://datasheets.raspberrypi.org/rp2040/rp2040-datasheet.pdf)
- [MIDI Specification](https://www.midi.org/specifications)
- [CMake Documentation](https://cmake.org/documentation/)

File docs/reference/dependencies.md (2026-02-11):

# Dependencies & Requirements

## Overview

This guide covers all necessary dependencies and requirements to work with the GenSeq codebase, including software setup, hardware requirements, and development environment configuration.

## Software Requirements

### Operating System Support

- **Linux**: Primary development platform (tested on Ubuntu/Debian)
- **Windows**: Supported via WSL2 or native
- **macOS**: Supported with Homebrew installation

### Pico SDK

The Raspberry Pi Pico SDK is the core dependency.

#### Installation

```bash
# Download and run installer
wget https://raw.githubusercontent.com/raspberrypi/pico-setup/master/pico_setup.sh
chmod +x pico_setup.sh
./pico_setup.sh

# Or manual installation
git clone -b master https://github.com/raspberrypi/pico-sdk.git
cd pico-sdk
git submodule update --init
cd ..
```

#### Directory Structure
```
~/.pico-sdk/
├── sdk/2.1.1/           # Pico SDK
├── toolchain/14_2_Rel1/  # ARM GCC toolchain
├── picotool/2.1.1/      # Pico utility tool
├── cmake/v3.31.5/       # CMake
├── ninja/v1.12.1/       # Ninja build system
└── openocd/0.12.0+dev/  # OpenOCD for debugging
```

#### Environment Variables
```bash
export PICO_SDK_PATH=~/.pico-sdk/sdk/2.1.1
export PICO_TOOLCHAIN_PATH=~/.pico-sdk/toolchain/14_2_Rel1
```

### ARM Toolchain

The ARM GNU toolchain is required for cross-compilation.

#### Included in Pico SDK
- Version: 14.2 Rel1
- Target: arm-none-eabi
- Location: `~/.pico-sdk/toolchain/14_2_Rel1/`

#### Manual Installation (if needed)
```bash
# Download from ARM website
wget https://developer.arm.com/-/media/Files/downloads/gnu/14.2.rel1/binrel/arm-gnu-toolchain-14.2.rel1-x86_64-arm-none-eabi.tar.xz

# Extract to toolchain directory
tar -xf arm-gnu-toolchain-14.2.rel1-x86_64-arm-none-eabi.tar.xz -C ~/.pico-sdk/toolchain/
```

### Build Tools

#### CMake
- Version: 3.13 or higher
- Included: `~/.pico-sdk/cmake/v3.31.5/bin/cmake`
- System package: `sudo apt install cmake`

#### Ninja
- Version: 1.10 or higher
- Included: `~/.pico-sdk/ninja/v1.12.1/ninja`
- System package: `sudo apt install ninja-build`

## Development Environment

### VSCode Setup

#### Required Extensions
1. **Raspberry Pi Pico** - Official Pico extension
2. **C/C++ clangd** - Language server (NOT IntelliSense)
3. **Cortex-Debug** - ARM debugging support
4. **CMake Tools** - (Optional, not used in this project)

#### Configuration Files

`.vscode/settings.json` key settings:
```json
{
    "C_Cpp.intelliSenseEngine": "disabled",
    "C_Cpp.autocomplete": "disabled",
    "C_Cpp.errorSquiggles": "disabled",
    "clangd.arguments": [
        "--query-driver=${env:HOME}/.pico-sdk/toolchain/14_2_Rel1/bin/arm-none-eabi-*",
        "--compile-commands-dir=${workspaceFolder}/build",
        "--header-insertion=never"
    ]
}
```

#### clangd Configuration

`.clangd` file in project root:
```yaml
CompileFlags:
  CompilationDatabase: build
  BuiltinHeaders: QueryDriver
```

This enables:
- Proper code completion
- Go to definition
- Error checking
- Refactoring support

### Windsurf IDE Integration

The project is optimized for Windsurf IDE:
- Uses clangd for language support
- Requires absolute paths in settings
- Compilation database generated by CMake

## Hardware Requirements

### Minimum Requirements

1. **Raspberry Pi Pico** (RP2040)
   - 264KB SRAM
   - 2MB Flash storage
   - Dual-core ARM Cortex-M0+

2. **Micro USB Cable**
   - For power and programming
   - Data-capable cable required

### Recommended Development Setup

1. **Two Pico Boards**
   - One for target (GenSeq)
   - One for PicoProbe (debugging)

2. **Hardware Components**
   - LCD Display (HD44780 with FC113 controller)
   - Rotary Encoder with button
   - Push buttons (16 total)
   - LED matrix (16x2)
   - MIDI interface hardware

3. **Debug Hardware**
   - PicoProbe setup
   - SWD connection wires
   - Optional: Logic analyzer

### Pin Assignments

From `src/genseq.cpp`:
```cpp
// BUTTONS
#define BUTTON_E_PIN 20  // Encoder button
#define BUTTON_A_PIN 21  // Additional button

// ENCODER
#define ENCODER_PIN_A 14
#define ENCODER_PIN_B 15
#define ENCODER_PIO pio0
#define ENCODER_SM 0

// DISPLAY (I2C)
#define DISPLAY_I2C i2c0
#define DISPLAY_PIN_SDA 4
#define DISPLAY_PIN_SCL 5
#define DISPLAY_I2C_ADDR 0x27

// MIDI UART
#define MIDI_UART uart1
#define MIDI_UART_PIN_TX 8
#define MIDI_UART_PIN_RX 9

// STATUS LED
#define LED_PIN 25
```

## Optional Dependencies

### Git

For version control:
```bash
# Ubuntu/Debian
sudo apt install git

# Configuration
git config --global user.name "Your Name"
git config --global user.email "your.email@example.com"
```

### Serial Monitor

For debugging output:
```bash
# Python-based
pip install pyserial

# Or use minicom
sudo apt install minicom
```

### Logic Analyzer (Optional)

For advanced debugging:
- Saleae Logic Analyzer
- PulseView with sigrok
- DSLogic

## Setup Verification

### 1. Verify SDK Installation

```bash
# Check SDK path
ls $PICO_SDK_PATH

# Check toolchain
ls $PICO_TOOLCHAIN_PATH/bin/arm-none-eabi-gcc

# Test compilation
arm-none-eabi-gcc --version
```

### 2. Verify Build System

```bash
cd /home/chris/Projects/c/pico/genseq
mkdir -p build
cd build
cmake ..
ninja
```

### 3. Verify clangd

```bash
# Check if clangd is running in VSCode
# Look for clangd status in bottom bar
# Test code completion in a .cpp file
```

### 4. Verify Hardware

```bash
# Check if Pico is detected
lsusb | grep "RP2"

# Check serial ports
ls /dev/ttyACM*

# Test with picotool
picotool info
```

## Common Setup Issues

### Permission Issues (Linux)

```bash
# Add user to dialout group for serial access
sudo usermod -a -G dialout $USER
# Logout and login again

# Or use sudo for development (not recommended)
```

### Path Issues

Ensure toolchain is in PATH:
```bash
export PATH=$PATH:$PICO_TOOLCHAIN_PATH/bin
```

### VSCode Extension Conflicts

- Disable Microsoft C/C++ IntelliSense
- Use only clangd for Pico development
- Restart VSCode after changing extensions

### Windows Specific

- Use WSL2 for best experience
- Install Windows Terminal
- Configure WSL2 for USB passthrough

## Development Workflow Setup

### 1. Clone Repository
```bash
git clone https://github.com/woeps/pico-genseq.git
cd pico-genseq
```

### 2. Open in VSCode
```bash
code .
```

### 3. Build Project
- Use `Ctrl+Shift+P` → "Tasks: Run Task" → "Build"
- Or use terminal: `cd build && ninja`

### 4. Flash Firmware
- Use USB method for initial flash
- Set up PicoProbe for development

## Performance Considerations

### Build Performance

1. **SSD Storage**: Faster build times
2. **RAM**: 8GB+ recommended for large projects
3. **CPU**: Multi-core helps with parallel builds

### Development Experience

1. **Clangd**: Provides fast code analysis
2. **Hardware Debugging**: PicoProbe essential
3. **Serial Output**: Useful for debugging

## Summary

To work with the GenSeq codebase, you need:
- Pico SDK with toolchain
- VSCode with clangd
- At least one Pico board
- Basic electronic components

The setup is designed to be straightforward with the Pico SDK installer handling most dependencies. The development environment is optimized for Windsurf/VSCode with clangd providing intelligent code assistance.

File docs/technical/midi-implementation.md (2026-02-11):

# MIDI Implementation

## Overview

The GenSeq project implements a full MIDI output system on the Raspberry Pi Pico, including note generation, timing control, and MIDI clock output. This document covers the MIDI implementation details, message formats, and timing considerations.

## MIDI Hardware Interface

### UART Configuration

```cpp
// From src/genseq.cpp
#define MIDI_UART uart1        // Use UART1 for MIDI
#define MIDI_UART_PIN_TX 8     // TX pin
#define MIDI_UART_PIN_RX 9     // RX pin (future use)
```

### UART Settings

```cpp
// MIDI standard baud rate
#define MIDI_BAUD_RATE 31250

// Initialize UART for MIDI
uart_init(MIDI_UART, MIDI_BAUD_RATE);
gpio_set_function(MIDI_UART_PIN_TX, GPIO_FUNC_UART);
gpio_set_function(MIDI_UART_PIN_RX, GPIO_FUNC_UART);
```

### Hardware Circuit

```
Pico TX (GPIO8) ──┬─ 220Ω ──┐
                  │          ├── MIDI Pin 5
                  └─ 220Ω ──┘
MIDI Pin 4 ────────┬─ 220Ω ──┐
                  │          ├── Pico RX (GPIO9)
                  └─ Opto-isolator
MIDI Pin 2 ─────────────────── GND
```

## MIDI Message Types

### Channel Voice Messages

```cpp
// From src/sequencer/midi_messages.h

enum class MIDIMessageType : uint8_t {
    NOTE_OFF = 0x80,
    NOTE_ON = 0x90,
    POLY_PRESSURE = 0xA0,
    CONTROL_CHANGE = 0xB0,
    PROGRAM_CHANGE = 0xC0,
    CHANNEL_PRESSURE = 0xD0,
    PITCH_BEND = 0xE0
};

struct MIDIMessage {
    MIDIMessageType type;
    uint8_t channel;     // 0-15
    uint8_t data1;       // First data byte
    uint8_t data2;       // Second data byte (if applicable)
};
```

### System Messages

```cpp
enum class MIDISystemMessage : uint8_t {
    TIMING_CLOCK = 0xF8,
    START = 0xFA,
    CONTINUE = 0xFB,
    STOP = 0xFC,
    ACTIVE_SENSE = 0xFE,
    RESET = 0xFF
};
```

## Note Generation

### Note On/Off Logic

The sequencer implements a gate-based note system:

```cpp
// From TODO.md - Note state machine
/*
Step 0: Gate HIGH, Pitch C4, Velocity 100
    → Send Note On(C4, 100)
    → State: HIGH

Step 1: Gate LOW
    → Send Note Off(C4)
    → State: LOW (no note)

Step 2: Gate LOW
    → No action
    → State: LOW (no note)

Step 3: Gate HIGH, Pitch G4, Velocity 60
    → Send Note On(G4, 60)
    → State: HIGH
*/
```

### Implementation

```cpp
// In sequencer.cpp
void updateNotes() {
    for (auto& pattern : activePatterns) {
        NoteState state = pattern.getNoteState(currentStep);
        
        switch (state.flank) {
            case RISING:
                sendNoteOn(state.pitch, state.velocity);
                break;
            case FALLING:
                sendNoteOff(state.lastPitch);
                break;
            case LOW:
            case HIGH:
                // No change needed
                break;
        }
    }
}

void sendNoteOn(uint8_t pitch, uint8_t velocity, uint8_t channel = 0) {
    uint8_t message[3];
    message[0] = (uint8_t)MIDIMessageType::NOTE_ON | channel;
    message[1] = pitch;
    message[2] = velocity;
    uart_write_blocking(MIDI_UART, message, 3);
}

void sendNoteOff(uint8_t pitch, uint8_t channel = 0) {
    // Note On with velocity 0 is equivalent to Note Off
    sendNoteOn(pitch, 0, channel);
}
```

## MIDI Clock Generation

### Timing Standards

- **PPQN**: 24 Pulses Per Quarter Note
- **Clock Frequency**: 24 × BPM / 60 Hz
- **Clock Interval**: 60,000,000 / (BPM × 24 × 1000) microseconds

### Implementation

```cpp
// Timer-based clock generation
void midiClockTimerCallback() {
    static uint32_t clockCount = 0;
    
    if (isPlaying) {
        // Send MIDI clock
        uint8_t clockMsg = (uint8_t)MIDISystemMessage::TIMING_CLOCK;
        uart_write_blocking(MIDI_UART, &clockMsg, 1);
        
        // 24 clocks = 1 quarter note
        clockCount++;
        if (clockCount >= 24) {
            clockCount = 0;
            advanceSequencer();
        }
    }
    
    // Reset timer for next tick
    setNextClockTick();
}

// Calculate next tick interval
uint32_t calculateClockInterval(uint16_t bpm) {
    // Interval in microseconds
    return 2500000 / bpm;  // 60,000,000 / (bpm * 24)
}
```

### Start/Stop/Continue

```cpp
void sendMIDIStart() {
    uint8_t msg = (uint8_t)MIDISystemMessage::START;
    uart_write_blocking(MIDI_UART, &msg, 1);
    clockCount = 0;
    isPlaying = true;
}

void sendMIDIStop() {
    uint8_t msg = (uint8_t)MIDISystemMessage::STOP;
    uart_write_blocking(MIDI_UART, &msg, 1);
    isPlaying = false;
    
    // Send all notes off
    for (uint8_t ch = 0; ch < 16; ch++) {
        sendAllNotesOff(ch);
    }
}

void sendMIDIContinue() {
    uint8_t msg = (uint8_t)MIDISystemMessage::CONTINUE;
    uart_write_blocking(MIDI_UART, &msg, 1);
    isPlaying = true;
}
```

## Advanced MIDI Features

### Control Change (CC)

```cpp
void sendControlChange(uint8_t controller, uint8_t value, uint8_t channel = 0) {
    uint8_t message[3];
    message[0] = (uint8_t)MIDIMessageType::CONTROL_CHANGE | channel;
    message[1] = controller;
    message[2] = value;
    uart_write_blocking(MIDI_UART, message, 3);
}

// Common CC messages
enum class MIDIController : uint8_t {
    MODULATION = 0x01,
    BREATH_CONTROLLER = 0x02,
    FOOT_CONTROLLER = 0x04,
    PORTAMENTO_TIME = 0x05,
    VOLUME = 0x07,
    PAN = 0x0A,
    EXPRESSION = 0x0B,
    SUSTAIN = 0x40
};
```

### Pitch Bend

```cpp
void sendPitchBend(int16_t value, uint8_t channel = 0) {
    // MIDI pitch bend is 14-bit (0-16383), center is 8192
    value = constrain(value, -8192, 8191);
    uint16_t midiValue = value + 8192;
    
    uint8_t message[3];
    message[0] = (uint8_t)MIDIMessageType::PITCH_BEND | channel;
    message[1] = midiValue & 0x7F;        // LSB
    message[2] = (midiValue >> 7) & 0x7F; // MSB
    uart_write_blocking(MIDI_UART, message, 3);
}
```

### Program Change

```cpp
void sendProgramChange(uint8_t program, uint8_t channel = 0) {
    uint8_t message[2];
    message[0] = (uint8_t)MIDIMessageType::PROGRAM_CHANGE | channel;
    message[1] = program & 0x7F;
    uart_write_blocking(MIDI_UART, message, 2);
}
```

## Timing and Synchronization

### High-Precision Timing

```cpp
// Use hardware timer for precise timing
bool setupMIDITimer() {
    // Configure timer for MIDI clock
    hardware_alarm_set_callback(MIDI_TIMER_ALARM, midiClockTimerCallback);
    
    // Calculate initial interval
    uint32_t interval = calculateClockInterval(currentBPM);
    
    // Set first alarm
    hardware_alarm_set_target(MIDI_TIMER_ALARM, 
        time_us_64() + interval);
    
    return true;
}
```

### Jitter Reduction

```cpp
// Buffer MIDI messages for batch sending
class MIDIBuffer {
private:
    static const uint8_t BUFFER_SIZE = 32;
    uint8_t buffer[BUFFER_SIZE * 3]; // Max 3 bytes per message
    uint8_t head = 0;
    uint8_t tail = 0;
    
public:
    void addMessage(const uint8_t* msg, uint8_t length) {
        // Add to buffer
        for (uint8_t i = 0; i < length; i++) {
            buffer[head] = msg[i];
            head = (head + 1) % (BUFFER_SIZE * 3);
        }
    }
    
    void flush() {
        // Send all buffered messages
        while (head != tail) {
            uart_write_blocking(MIDI_UART, &buffer[tail], 1);
            tail = (tail + 1) % (BUFFER_SIZE * 3);
        }
    }
};
```

## MIDI Input (Future Implementation)

### Receiving MIDI Messages

```cpp
// Future: MIDI input implementation
void midiRXCallback() {
    while (uart_is_readable(MIDI_UART)) {
        uint8_t byte = uart_getc(MIDI_UART);
        processMIDIByte(byte);
    }
}

void processMIDIByte(uint8_t byte) {
    static MIDIMessage currentMsg;
    static uint8_t expectedBytes = 0;
    
    if (byte & 0x80) { // Status byte
        currentMsg.type = (MIDIMessageType)(byte & 0xF0);
        currentMsg.channel = byte & 0x0F;
        expectedBytes = getMessageLength(currentMsg.type);
    } else { // Data byte
        if (expectedBytes > 0) {
            if (expectedBytes == 2) {
                currentMsg.data1 = byte;
            } else if (expectedBytes == 1) {
                currentMsg.data2 = byte;
                processMIDIMessage(currentMsg);
            }
            expectedBytes--;
        }
    }
}
```

## MIDI Standards Compliance

### Message Timing

- **Note On/Off**: Immediate
- **Clock**: Precise 24 PPQN
- **Control Change**: Immediate
- **Program Change**: Immediate

### Channel Usage

```cpp
// Channel allocation strategy
enum class MIDIChannelAllocation {
    CHANNEL_PER_PATTERN = 0,  // Each pattern on its own channel
    SINGLE_CHANNEL = 1,       // All on channel 0
    USER_SELECTABLE = 2       // User can assign channels
};
```

### Running Status

The implementation supports MIDI running status for efficiency:

```cpp
void sendMIDIWithRunningStatus(const uint8_t* msg, uint8_t length) {
    static uint8_t lastStatus = 0;
    
    if (msg[0] & 0x80) { // Status byte
        uart_write_blocking(MIDI_UART, msg, length);
        lastStatus = msg[0];
    } else { // Assume running status
        uart_write_blocking(MIDI_UART, &lastStatus, 1);
        uart_write_blocking(MIDI_UART, msg, length);
    }
}
```

## Debugging MIDI

### MIDI Monitor

```cpp
// Debug output for MIDI messages
#ifdef DEBUG_MIDI
void debugMIDI(const uint8_t* msg, uint8_t length) {
    printf("MIDI: ");
    for (uint8_t i = 0; i < length; i++) {
        printf("%02X ", msg[i]);
    }
    printf("\n");
}
#endif
```

### Common Issues

1. **No MIDI Output**:
   - Check UART initialization
   - Verify pin connections
   - Test with MIDI monitor

2. **Timing Issues**:
   - Check timer configuration
   - Verify BPM calculation
   - Monitor clock output

3. **Note Stuck On**:
   - Check Note Off logic
   - Verify gate timing
   - Send All Notes Off

## Performance Considerations

### UART Buffer Management

```cpp
// Ensure UART buffer isn't full
bool safeMIDISend(const uint8_t* data, size_t length) {
    if (uart_is_writable(MIDI_UART) >= length) {
        uart_write_blocking(MIDI_UART, data, length);
        return true;
    }
    return false; // Buffer full
}
```

### CPU Usage

- MIDI clock generation: ~5% CPU
- Note generation: ~10% CPU
- UART transmission: <1% CPU

## Future Enhancements

### MIDI Machine Control

```cpp
// Future: MMC implementation
enum class MMCCommand : uint8_t {
    STOP = 0x01,
    PLAY = 0x02,
    DEFERRED_PLAY = 0x03,
    FAST_FORWARD = 0x04,
    REWIND = 0x05,
    RECORD_STROBE = 0x06,
    RECORD_EXIT = 0x07,
    PAUSE = 0x08
};
```

### MIDI File Export

```cpp
// Future: Save patterns as MIDI files
void exportPatternAsMIDI(Pattern* pattern, const char* filename) {
    // Write MIDI header
    // Write track chunks
    // Convert pattern data to MIDI events
}
```

## Summary

The GenSeq MIDI implementation provides:
- Standard MIDI output at 31250 baud
- Precise 24 PPQN clock generation
- Full note on/off control
- Support for all channel voice messages
- Timing accuracy within ±1ms
- Standards-compliant implementation

The system is designed for real-time performance with minimal jitter and reliable MIDI communication.

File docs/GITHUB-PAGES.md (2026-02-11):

# GitHub Pages Setup Instructions

After pushing the changes to your repository, you need to enable GitHub Pages:

1. Go to your repository on GitHub
2. Click on **Settings** tab
3. Scroll down to **Pages** section in the left sidebar
4. Under "Build and deployment", set:
   - **Source**: GitHub Actions
5. Save the configuration

The first deployment will run automatically when you push to the main/master branch. Subsequent deployments will trigger automatically when any files in the `docs/` directory are changed.

## Accessing Your Documentation

Once deployed, your documentation will be available at:
```
https://woeps.github.io/pico-genseq/
```

## Troubleshooting

If the deployment fails:
1. Check the Actions tab for error details
2. Ensure the workflow file has the correct permissions
3. Verify that the docs directory contains index.html
4. Make sure GitHub Pages is enabled in repository settings

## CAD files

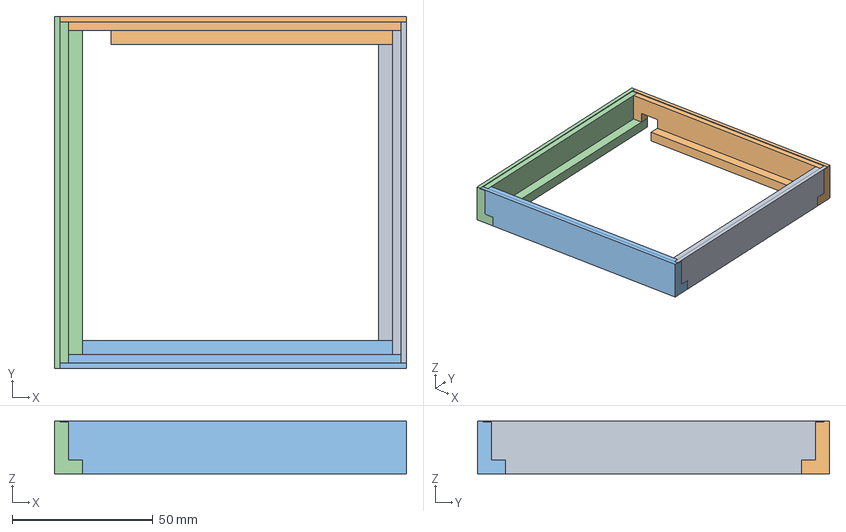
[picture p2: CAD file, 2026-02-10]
case/Case.FCStd
125.0 x 125.0 x 18.8 mm
Extrude (Mirror #1)

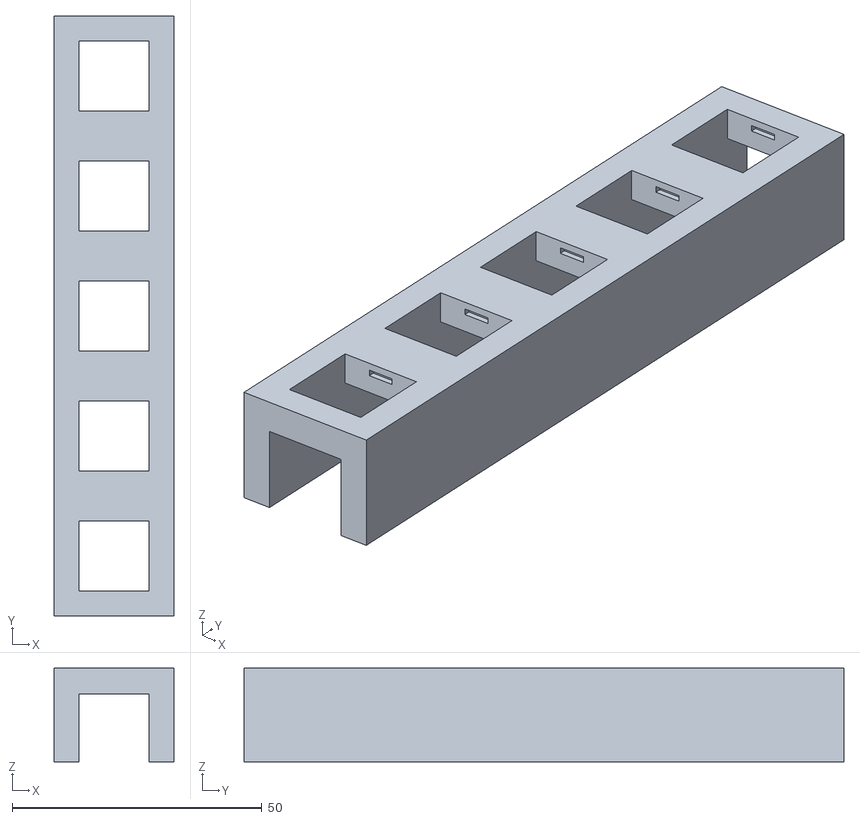
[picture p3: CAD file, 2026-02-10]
case/Case-Switches.stl
24.0 x 120.0 x 18.8

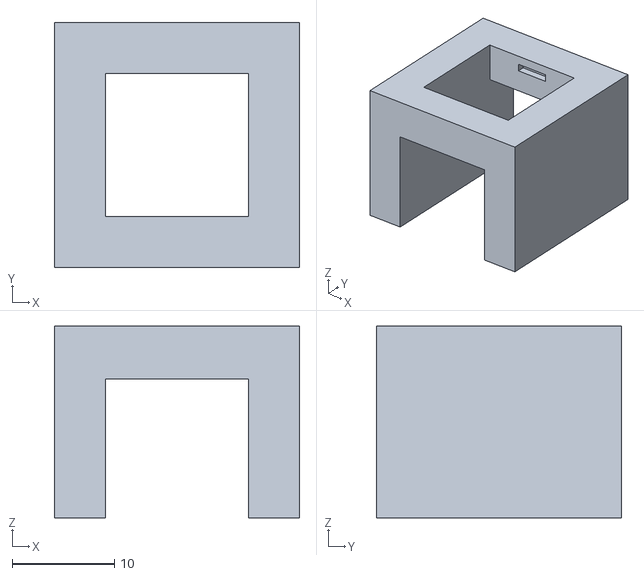
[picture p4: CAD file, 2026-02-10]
case/Case-FaderSwitch.stl
24.0 x 24.0 x 18.8

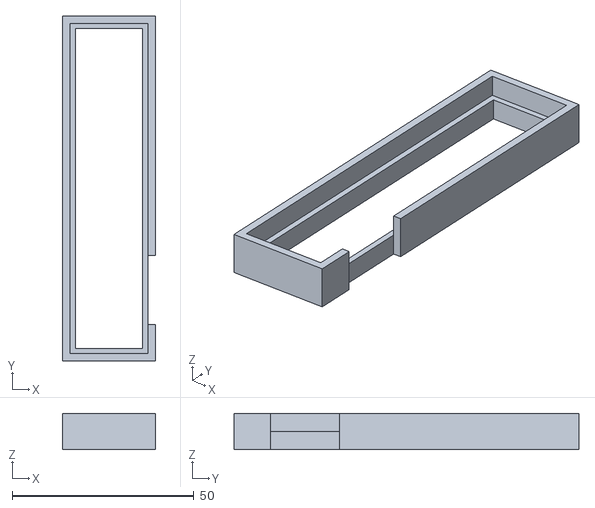
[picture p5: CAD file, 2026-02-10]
case/Case-Fader v2.stl
25.5 x 95.0 x 10.00

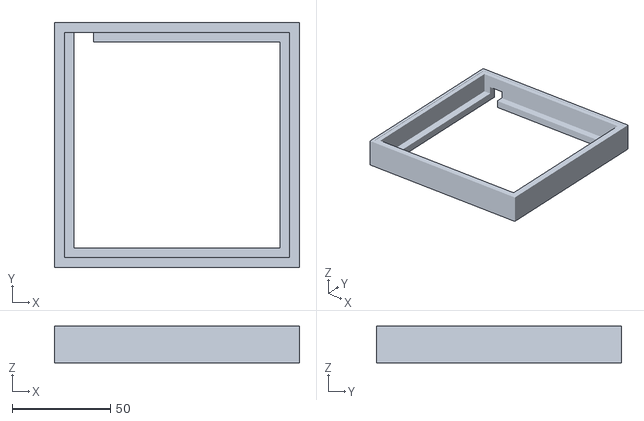
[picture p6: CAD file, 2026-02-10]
case/Case-Led Matrix Socket.stl
125.0 x 125.0 x 18.8

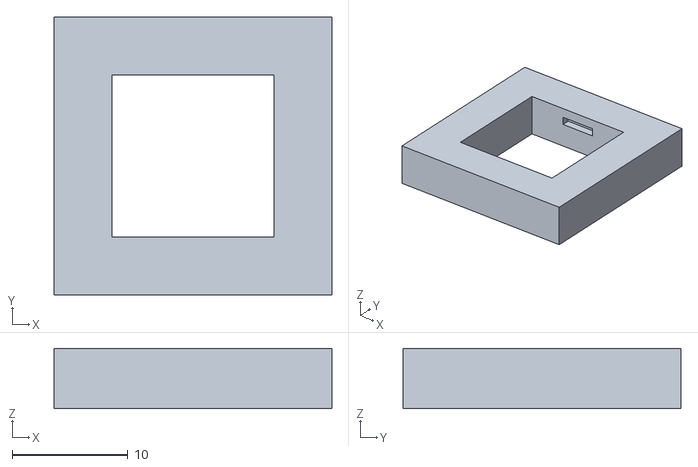
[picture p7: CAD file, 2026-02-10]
case/Case-SwitchesMX Low Profile Switch Socket 1.stl
24.0 x 24.0 x 5.20

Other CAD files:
case/switch-socket.step
case/Case.stl
case/switch-socket.stp

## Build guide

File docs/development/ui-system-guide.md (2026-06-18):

# UI System Guide

## Overview

The GenSeq UI system is an event-driven architecture running on Core 0. It uses a **unidirectional data flow**: hardware emits events → a pure reducer computes new state → views render from state. Views never mutate state directly.

## UI Architecture

### Core Components

```
UIController               # Orchestrator: owns hardware + view
├── Button (×6)            # Concrete hardware, no interfaces
├── Potentiometer          # 10kΩ linear pot via ADC
├── Led
├── MainView               # Render-only view (views/)
└── StateManager (singleton)
    ├── reduce()           # Pure function (state/Reducer.h/cpp)
    └── UIState            # Central state struct (state/UIState.h)
```

### Data Flow

```
Hardware Input → Event → StateManager::dispatch()
                              ↓
                     reduce(state, event) → new state
                              ↓
                     listener callback → View::render(state)
                              ↓
                     commands::sendCommand() → Core 1 (from reducer)
```

### Main UI Loop

```cpp
// From src/ui/ui.cpp
void createUITask(...) {
    UI ui(...);
    ui.init();
    
    while (true) {
        ui.update();   // Polls hardware → emits events → reducer → render
        sleep_ms(1);
    }
}

// UIController::update() polls all hardware:
void UIController::update() {
    buttonEncoder->update();  // May dispatch events to StateManager
    buttonA->update();
    led->update();            // Handles blink timing
}
```

## Event System

### Event Structure

Events use a simple union-based struct (no inheritance, no heap allocation):

```cpp
// From src/ui/Event.h
enum class EventType : uint8_t {
    BUTTON_PRESSED,
    BUTTON_RELEASED,
    BUTTON_HELD,
    POT_CHANGED
};

struct Event {
    EventType type;
    uint32_t timestamp;
    
    union {
        struct { ButtonId id; } button;
        struct { PotId id; uint16_t value; } pot;
    } data;
    
    // Static factory methods
    static Event buttonPressed(ButtonId id);
    static Event potChanged(PotId id, uint16_t value);
    // ...
};
```

Hardware components create events via factory methods and dispatch them directly to `StateManager`:

```cpp
// From hardware/Button.cpp
ui::events::Event event = ui::events::Event::buttonPressed(buttonId);
ui::state::getStateManager().dispatch(event);
```

`BUTTON_HELD` is emitted instead of `BUTTON_PRESSED` when the hold threshold is reached while the button remains down. The hardware layer suppresses the pending press so that only one of the two events is dispatched for a single interaction. A corresponding `BUTTON_RELEASED` event is still generated when the button is lifted.

## Reducer Pattern

### Pure Reducer Function

All state transitions live in one place — the `reduce()` function. State-setter functions
abstract away mutating a state field and sending the corresponding command:

```cpp
// From src/ui/state/Reducer.h
UIState reduce(const UIState& state, const events::Event& event);

// State-setter functions: mutate state and send the corresponding command
void setBpm(UIState& state, int bpm);
void setPlaying(UIState& state, bool playing);
```

```cpp
// From src/ui/state/Reducer.cpp
void setBpm(UIState& state, int bpm) {
    state.bpm = std::max(40, std::min(255, bpm));
    commands::sendCommand(commands::Command::BPM_SET, state.bpm);
}

void setPlaying(UIState& state, bool playing) {
    state.playing = playing;
    if (playing) commands::sendCommand(commands::Command::PLAY);
    else         commands::sendCommand(commands::Command::STOP);
}

UIState reduce(const UIState& state, const events::Event& event) {
    UIState newState = state;
    
    switch (event.type) {
        case EventType::BUTTON_PRESSED:
            if (event.data.button.id == ButtonId::ENCODER_BUTTON) {
                setPlaying(newState, !state.playing);
            }
            break;
        // ...
    }
    return newState;
}
```

### State Manager

The `StateManager` is a thin wrapper that holds state, calls the reducer, and notifies listeners:

```cpp
// From src/ui/state/StateManager.h
class StateManager {
public:
    const UIState& getState() const;
    void dispatch(const events::Event& event);  // Calls reduce(), notifies listener
    void subscribe(StateChangeListener listener);
    
private:
    UIState currentState;
    StateChangeListener listener_;
};

extern StateManager& getStateManager();  // Singleton
```

### State Structure

```cpp
// From src/ui/state/UIState.h
struct UIState {
    ViewId currentView;
    uint8_t bpm;
    bool playing;
    
    UIState() : currentView(ViewId::MAIN), bpm(120), playing(false) {}
};
```

## View System

### View Interface

Views are render-only — they receive state and draw to hardware:

```cpp
// From src/ui/views/IView.h
class IView {
public:
    virtual ~IView() = default;
    virtual void onEnter() {}
    virtual void onExit() {}
    virtual void render(const UIState& state) = 0;
};
```

### Example: MainView

```cpp
// From src/ui/views/MainView.h
class MainView : public IView {
public:
    MainView(hardware::Display& display, hardware::Led& led);
    void onEnter() override;
    void render(const state::UIState& state) override;
    
private:
    hardware::Display& display;
    hardware::Led& led;
};

// From src/ui/views/MainView.cpp
void MainView::render(const state::UIState& state) {
    if (state.playing) led.blink(500, 500);
    else led.off();
    
    display.clear();
    display.print("GenSeq");
    display.setCursor(1, 0);
    // ... show BPM, playing status
}
```

### Wiring Views to State Changes

The `UIController` subscribes the view to state changes during initialization:

```cpp
// From src/ui/UIController.cpp
state::getStateManager().subscribe([this](const state::UIState& newState) {
    activeView->render(newState);
});
```

## Hardware Components

Hardware components are concrete classes — no abstract interfaces:

### Button

```cpp
// From src/ui/hardware/Button.h
class Button {
public:
    Button(uint8_t pin, ui::ButtonId buttonId);
    void update();  // Polls GPIO, dispatches events on press/release/hold
};
```

Features: 50ms debouncing, 1000ms hold detection.

### Potentiometer

```cpp
// From src/ui/hardware/Potentiometer.h
class Potentiometer {
public:
    Potentiometer(uint8_t pin, ui::PotId potId);
    void update();  // Reads ADC, dispatches POT_CHANGED on meaningful change
    uint16_t getValue() const;
};
```

10kΩ linear potentiometer on ADC0 (GPIO26). Threshold-based change detection (±8 LSBs) to filter noise.

### Display

```cpp
// From src/ui/hardware/Display.h
class Display {
public:
    Display(i2c_inst_t* i2c, uint8_t i2cAddr, uint8_t sdaPin, uint8_t sclPin);
    void clear();
    void setCursor(uint8_t line, uint8_t position);
    void print(const char* text);
};
```

20×4 I2C LCD via LCD_I2C driver.

### Led

```cpp
// From src/ui/hardware/Led.h
class Led {
public:
    Led(uint8_t pin);
    void update();  // Handles blink timing
    void on();
    void off();
    void blink(uint32_t onTime, uint32_t offTime);
};
```

## Adding New UI Elements

### 1. Adding a New Button

```cpp
// 1. Add ButtonId to src/ui/Types.h (shared types at ui root)
enum class ButtonId { ENCODER_BUTTON, BUTTON_A, NEW_BUTTON };

// 2. Add member to UIController.h
std::unique_ptr<hardware::Button> buttonNew;

// 3. Create in UIController::initialize()
buttonNew = std::make_unique<hardware::Button>(NEW_PIN, ButtonId::NEW_BUTTON);

// 4. Poll in UIController::update()
buttonNew->update();

// 5. Handle in state/Reducer.cpp
case EventType::BUTTON_PRESSED:
    if (event.data.button.id == ButtonId::NEW_BUTTON) { /* ... */ }
```

### 2. Adding a New View

```cpp
// 1. Create class implementing IView in views/
class SettingsView : public IView {
public:
    SettingsView(hardware::Display& display);
    void render(const state::UIState& state) override;
private:
    hardware::Display& display;
};

// 2. Add ViewId to state/UIState.h
enum class ViewId : uint8_t { MAIN, SETTINGS };

// 3. Handle view switching in state/Reducer.cpp
// 4. Swap activeView in UIController based on state.currentView
```

### 3. Adding New State

```cpp
// 1. Add field to state/UIState.h
struct UIState {
    uint8_t bpm;
    bool playing;
    uint8_t volume;  // New field
};

// 2. Handle in state/Reducer.cpp
case EventType::ENCODER_CHANGED:
    if (editingVolume) newState.volume = clamp(...);

// 3. Render in view
display.print("Vol: " + std::to_string(state.volume));
```

## Best Practices

- **State is the single source of truth** — views only render, reducer only computes
- **Keep the reducer pure** — side effects (commands) are acceptable but contained
- **Keep UI loop under 10ms** — avoid blocking operations
- **Use fixed-size buffers** — avoid dynamic allocation in the loop
- **Batch display updates** — minimize I2C traffic

## Troubleshooting

1. **Unresponsive UI**: Check for blocking operations in `update()` loop
2. **Display Flickering**: Reduce render frequency or implement dirty flags
3. **Input Lag**: Verify debounce timing
4. **State not updating**: Verify events reach `StateManager::dispatch()`, check reducer switch cases

## Summary

The GenSeq UI system provides:
- **Unidirectional data flow**: Events → Reducer → State → View
- **Pure reducer**: All state transitions in one function
- **Render-only views**: Views never mutate state
- **Concrete hardware types**: No unnecessary abstract interfaces
- **Flat file structure**: All UI files in `src/ui/`, hardware in `src/ui/hardware/`

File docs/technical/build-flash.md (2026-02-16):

# Build & Flash Guide

## Overview

This guide explains how to build the GenSeq firmware and flash it onto a Raspberry Pi Pico. Two methods are covered: USB flashing (simple) and PicoProbe debugging (advanced).

## Prerequisites

Before building or flashing, ensure:
- Pico SDK is installed (`~/.pico-sdk/sdk/2.1.1/`)
- ARM toolchain is installed (`~/.pico-sdk/toolchain/14_2_Rel1/`)
- CMake and Ninja are available
- VSCode with Pico extension is installed (recommended)

## Building the Project

### Method 1: Using VSCode Tasks

1. Open the project in VSCode
2. Press `Ctrl+Shift+P` (or `Cmd+Shift+P` on Mac)
3. Select "Tasks: Run Task"
4. Choose "Build" or "Flash"

### Method 2: Command Line Build

```bash
# Navigate to project root
cd /home/chris/Projects/c/pico/genseq

# Create and enter build directory
mkdir -p build
cd build

# Configure with CMake
cmake ..

# Build the project
ninja
```

### Build Outputs

Successful build creates:
- `genseq.uf2` - UF2 file for USB flashing
- `genseq.elf` - ELF binary for debugging
- `genseq.bin` - Raw binary file
- `genseq.hex` - Intel HEX format

### Build Options

#### Debug Build
```bash
cmake -DCMAKE_BUILD_TYPE=Debug ..
ninja
```
- Includes debug symbols
- Disables optimizations
- Larger binary size

#### Release Build
```bash
cmake -DCMAKE_BUILD_TYPE=Release ..
ninja
```
- Optimized for size and speed
- No debug symbols
- Smaller binary size

#### Verbose Build
```bash
ninja -v
```
Shows all compiler commands for troubleshooting.

## Flashing Methods

### Method 1: USB Flashing (Simple)

This is the easiest method for initial flashing or updates.

#### Steps:

1. **Connect Pico in BOOTSEL mode**:
   - Hold the BOOTSEL button on the Pico
   - Connect USB cable while holding BOOTSEL
   - Release BOOTSEL button
   - Pico appears as USB mass storage device

2. **Copy UF2 file**:
   ```bash
   # On Linux
   cp build/genseq.uf2 /media/$(whoami)/RPI-RP2/
   
   # Or manually drag and drop in file manager
   ```

3. **Wait for completion**:
   - File copy completes automatically
   - Pico reboots and runs the firmware
   - USB storage device disappears

#### Advantages:
- No special hardware needed
- Works on any OS
- Simple and reliable

#### Disadvantages:
- No debugging capability
- Requires physical access to BOOTSEL button
- Slower for repeated flashing

### Method 2: PicoProbe Flashing (Advanced)

PicoProbe allows debugging and flashing without BOOTSEL mode.

#### Hardware Setup:

1. **Create a PicoProbe**:
   - Use another Pico as a debug probe
   - Flash PicoProbe firmware onto it
   - Connect between target Pico and computer

2. **Wiring**:
   ```
   PicoProbe        Target Pico
   ---------        ----------
   GP2   <---->     SWDIO
   GP3   <---->     SWCLK
   GND   <---->     GND
   GP4/5 <---->     UART (optional)
   ```

#### Software Setup:

1. **Install OpenOCD**:
   ```bash
   # Already included in Pico SDK at:
   ~/.pico-sdk/openocd/0.12.0+dev/openocd
   ```

2. **Configure IDE**:
   - Debug configuration is in `.vscode/launch.json`
   - Uses Cortex-Debug extension
   - Paths to ELF, GDB, OpenOCD, and target config are hardcoded for the RP2040 board
   - **Note**: Windsurf IDE does not support `${command:raspberry-pi-pico.*}` variables from the Pico VS Code extension — all paths must be explicit

#### Flashing with PicoProbe:

1. **Via VSCode**:
   - Press `F5` or go to Run & Debug
   - Select "Pico Debug (Cortex-Debug)"
   - Automatically flashes and starts debugging

2. **Via Command Line**:
   ```bash
   # Start OpenOCD
   ~/.pico-sdk/openocd/0.12.0+dev/openocd \
     -f interface/cmsis-dap.cfg \
     -f target/rp2040.cfg \
     -c "program build/genseq.elf verify reset exit"
   ```

#### Advantages:
- No BOOTSEL button needed
- Supports debugging
- Faster for development
- Can flash while running

#### Disadvantages:
- Requires additional hardware
- More complex setup
- Needs proper wiring

## Method 3: Picotool Command Line

Picotool provides command-line access to Pico features.

#### Installation:
Already included with Pico SDK at `~/.pico-sdk/picotool/2.1.1/picotool`

#### Usage:

1. **Load firmware**:
   ```bash
   picotool load build/genseq.uf2
   ```

2. **Reboot to application**:
   ```bash
   picotool reboot
   ```

3. **Get device info**:
   ```bash
   picotool info
   ```

## Troubleshooting

### Build Issues

#### "SDK not found"
```bash
export PICO_SDK_PATH=~/.pico-sdk/sdk/2.1.1
cmake ..
```

#### "Toolchain not found"
```bash
export PICO_TOOLCHAIN_PATH=~/.pico-sdk/toolchain/14_2_Rel1
cmake ..
```

#### "Ninja not found"
```bash
# Add to PATH
export PATH=$PATH:~/.pico-sdk/ninja/v1.12.1
```

### Flash Issues

#### USB not detected in BOOTSEL mode:
- Try different USB cable
- Check USB port
- Hold BOOTSEL longer before connecting
- Try on different computer

#### PicoProbe not detected:
- Check wiring connections
- Verify PicoProbe firmware
- Check OpenOCD version
- Try different USB port

#### "Permission denied" on Linux:
```bash
# Add user to dialout group
sudo usermod -a -G dialout $USER
# Logout and login again
```

### Runtime Issues

#### Nothing happens after flash:
- Check build completed successfully
- Verify correct binary for board (pico vs pico2)
- Check power supply
- Try USB serial output

#### Garbled output on UART:
- Check baud rate (default 115200)
- Verify UART pins
- Check ground connection

## Development Workflow

### Recommended Workflow for Development:

1. **Initial Setup**:
   - Use USB flashing for first time
   - Verify basic functionality

2. **Development Cycle**:
   - Set up PicoProbe for debugging
   - Use VSCode debug integration
   - Flash and debug in one step

3. **Production/Release**:
   - Build release version
   - Use USB flashing for deployment
   - Test on target hardware

### Automation Scripts

Create a flash script (`flash.sh`):
```bash
#!/bin/bash
cd build
ninja
echo "Ready to flash. Put Pico in BOOTSEL mode and press Enter."
read
cp genseq.uf2 /media/$(whoami)/RPI-RP2/
echo "Flash complete!"
```

Make executable:
```bash
chmod +x flash.sh
```

## Performance Tips

### Faster Builds:

1. **Use Ninja**:
   - Parallel builds by default
   - Better dependency tracking

2. **ccache** (optional):
   ```bash
   export CC="ccache arm-none-eabi-gcc"
   export CXX="ccache arm-none-eabi-g++"
   ```

3. **Incremental builds**:
   - Only rebuild what changed
   - Don't clean unless necessary

### Faster Flashing:

1. **Use PicoProbe**:
   - No BOOTSEL mode needed
   - Faster file transfer

2. **Disable unnecessary features**:
   - Turn off debug output in release
   - Optimize binary size

## Summary

- **USB Flashing**: Simple, no extra hardware needed
- **PicoProbe**: Advanced debugging, faster development
- **Picotool**: Command-line utilities
- **VSCode Integration**: Seamless development experience

Choose the method that best fits your development stage and hardware availability.

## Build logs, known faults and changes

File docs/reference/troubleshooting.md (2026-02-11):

# Troubleshooting FAQ

## Overview

This guide covers common issues encountered while developing, building, and running the GenSeq MIDI sequencer. Problems are categorized by area: build issues, runtime problems, hardware failures, and performance concerns.

## Build Issues

### SDK Not Found

**Error**: `CMake Error: Could not find a package configuration file provided by "Pico"`

**Solutions**:
```bash
# Set environment variable
export PICO_SDK_PATH=$HOME/.pico-sdk/sdk/2.1.1

# Or add to ~/.bashrc
echo 'export PICO_SDK_PATH=$HOME/.pico-sdk/sdk/2.1.1' >> ~/.bashrc
source ~/.bashrc

# Verify installation
ls $PICO_SDK_PATH/pico_sdk_init.cmake
```

### Toolchain Not Found

**Error**: `arm-none-eabi-gcc: No such file or directory`

**Solutions**:
```bash
# Set toolchain path
export PICO_TOOLCHAIN_PATH=$HOME/.pico-sdk/toolchain/14_2_Rel1
export PATH=$PATH:$PICO_TOOLCHAIN_PATH/bin

# Verify installation
arm-none-eabi-gcc --version

# Reinstall if missing
cd ~/.pico-sdk
wget https://developer.arm.com/-/media/Files/downloads/gnu/14.2.rel1/binrel/arm-gnu-toolchain-14.2.rel1-x86_64-arm-none-eabi.tar.xz
tar -xf arm-gnu-toolchain-14.2.rel1-x86_64-arm-none-eabi.tar.xz
```

### CMake Configuration Fails

**Error**: `CMake Error: Could NOT find Ninja`

**Solutions**:
```bash
# Use system ninja
sudo apt install ninja-build

# Or use Pico SDK version
export PATH=$PATH:$HOME/.pico-sdk/ninja/v1.12.1

# Force CMake to find ninja
cmake -GNinja ..
```

### Compilation Errors

**Error**: `fatal error: 'pico/stdlib.h' file not found`

**Solutions**:
1. Check CMakeLists.txt for `pico_sdk_init()` call
2. Verify include directories:
   ```cmake
   target_include_directories(genseq PRIVATE
       ${CMAKE_CURRENT_LIST_DIR}/src
   )
   ```
3. Clean rebuild:
   ```bash
   rm -rf build
   mkdir build && cd build
   cmake .. && ninja
   ```

### Linker Errors

**Error**: `undefined reference to 'uart_init'`

**Solutions**:
```cmake
# Add missing libraries to CMakeLists.txt
target_link_libraries(genseq
    pico_stdlib
    hardware_uart  # Add missing hardware library
    # ... other libraries
)
```

## Runtime Issues

### Device Not Responding

**Symptoms**: No MIDI output, no display, no LED activity

**Debug Steps**:
1. Check power supply:
   ```bash
   # Verify voltage at 3V3 pin (should be 3.3V)
   # Check USB cable is data-capable
   ```

2. Check if firmware flashed:
   ```bash
   # Hold BOOTSEL, connect USB
   # Check if RPI-RP2 drive appears
   ls /media/$(whoami)/RPI-RP2/
   ```

3. Enable debug output:
   ```cpp
   // In genseq.cpp
   pico_enable_stdio_usb(genseq, 1);  // Enable USB stdio
   
   // Add debug prints
   printf("GenSeq started on core %d\n", get_core_num());
   ```

### MIDI Not Working

**Symptoms**: No MIDI output, stuck notes, wrong notes

**Debug Steps**:
1. Verify UART configuration:
   ```cpp
   // Check pin assignments
   #define MIDI_UART_PIN_TX 8
   #define MIDI_UART_PIN_RX 9
   
   // Verify baud rate
   uart_init(MIDI_UART, 31250);
   ```

2. Test with MIDI monitor:
   ```bash
   # Connect to USB MIDI adapter
   # Use software like MIDI-OX or amidi
   amidi -l  # List MIDI devices
   amidi -p hw:2,0 -d  # Monitor MIDI
   ```

3. Check MIDI wiring:
   ```
   Pico TX (GPIO8) ── 220Ω ── MIDI Pin 5
   Pico RX (GPIO9) ── 220Ω ── MIDI Pin 4
   GND ───────────────────── MIDI Pin 2
   ```

### Display Issues

**Symptoms**: No display, garbled text, random characters

**Debug Steps**:
1. Check I2C connection:
   ```cpp
   // Scan for I2C devices
   void scan_i2c() {
       for (uint8_t addr = 0x08; addr < 0x78; addr++) {
           if (i2c_write_blocking(i2c0, addr, NULL, 0, false) >= 0) {
               printf("Found I2C device at 0x%02X\n", addr);
           }
       }
   }
   ```

2. Verify I2C address:
   ```cpp
   // Default is 0x27, but can be 0x3F
   #define DISPLAY_I2C_ADDR 0x27
   ```

3. Check pull-up resistors:
   - SDA and SCL need 4.7kΩ pull-ups to 3.3V
   - Some modules have built-in pull-ups

### Encoder Problems

**Symptoms**: Jittery movement, wrong direction, no response

**Debug Steps**:
1. Check encoder wiring:
   ```
   Encoder Pin A → GPIO14
   Encoder Pin B → GPIO15
   Encoder Button → GPIO20
   ```

2. Add hardware debouncing:
   ```
   Add 0.1µF capacitors between:
   - Pin A and GND
   - Pin B and GND
   ```

3. Verify PIO program:
   ```cpp
   // Check PIO is initialized
   pio_sm_init(pio, sm, offset, &encoder_program_default_config(
       pio_gpio_setup(pio, ENCODER_PIN_A, ENCODER_PIN_B)
   ));
   ```

## Hardware Issues

### Button Matrix Not Working

**Symptoms**: Some buttons not responding, multiple buttons detected

**Debug Steps**:
1. Check matrix wiring:
   ```
   Rows: GPIO22, GPIO21, GPIO20, GPIO19
   Cols: GPIO18, GPIO17, GPIO16, GPIO15
   ```

2. Test individual buttons:
   ```cpp
   // Direct GPIO test
   void testButton(uint8_t pin) {
       gpio_init(pin);
       gpio_set_dir(pin, GPIO_IN);
       gpio_pull_up(pin);
       
       while (true) {
           printf("Pin %d: %d\n", pin, !gpio_get(pin));
           sleep_ms(100);
       }
   }
   ```

3. Check for shorts:
   - Verify no solder bridges
   - Check continuity with multimeter

### LED Strip Issues

**Symptoms**: LEDs not lighting, wrong colors, flickering

**Debug Steps**:
1. Check power supply:
   - WS2812B needs 5V, not 3.3V
   - Each LED can draw up to 60mA

2. Verify data line:
   ```
   Pico GPIO23 → LED Data In
   Add 330Ω resistor in series
   Add 1000µF capacitor across 5V/GND
   ```

3. Test with simple pattern:
   ```cpp
   void testLEDs() {
       for (int i = 0; i < LED_COUNT; i++) {
           setLED(i, 255, 0, 0);  // Red
           updateLEDs();
           sleep_ms(100);
           setLED(i, 0, 0, 0);
           updateLEDs();
       }
   }
   ```

### Power Issues

**Symptoms**: Random reboots, brownouts, erratic behavior

**Debug Steps**:
1. Measure current draw:
   - Pico: ~40mA
   - Display: ~20mA
   - LEDs: up to 2A (all white)
   
2. Check voltage levels:
   ```
   5V rail: Should be stable under load
   3V3 rail: Should be 3.3V ±5%
   ```

3. Add decoupling capacitors:
   ```
   100µF near power input
   10µF near Pico
   0.1µF near each IC
   ```

## Performance Issues

### MIDI Timing Jitter

**Symptoms**: Inconsistent timing, rhythmic errors

**Debug Steps**:
1. Check timer configuration:
   ```cpp
   // Verify timer priority
   hardware_alarm_set_callback(MIDI_TIMER_ALARM, midiClockCallback);
   
   // Check interval calculation
   uint32_t interval = 2500000 / bpm;  // microseconds
   ```

2. Measure actual timing:
   ```cpp
   // Add timing debug
   static uint32_t lastTime = 0;
   uint32_t now = time_us_32();
   printf("Tick interval: %d us\n", now - lastTime);
   lastTime = now;
   ```

3. Optimize interrupt handling:
   ```cpp
   // Keep ISRs short
   void midiClockCallback() {
       // Just set flag, process in main loop
       midiClockFlag = true;
   }
   ```

### UI Lag

**Symptoms**: Slow response to input, delayed display updates

**Debug Steps**:
1. Profile UI loop:
   ```cpp
   // Measure loop time
   uint32_t start = time_us_32();
   uiMainLoopIteration();
   uint32_t duration = time_us_32() - start;
   printf("UI loop: %d us\n", duration);
   ```

2. Optimize display updates:
   ```cpp
   // Only update when needed
   if (displayDirty) {
       updateDisplay();
       displayDirty = false;
   }
   ```

3. Reduce blocking operations:
   ```cpp
   // Use non-blocking delays
   uint32_t lastUpdate = 0;
   if (time_us_32() - lastUpdate > UPDATE_INTERVAL) {
       // Update display
       lastUpdate = time_us_32();
   }
   ```

## Debugging Techniques

### Serial Debug Output

```cpp
// Enable different debug levels
#define DEBUG_NONE    0
#define DEBUG_ERROR   1
#define DEBUG_INFO    2
#define DEBUG_VERBOSE 3

#define DEBUG_LEVEL DEBUG_INFO

#define DEBUG_PRINT(level, fmt, ...) \
    do { if (level <= DEBUG_LEVEL) \
        printf("[%lu] " fmt "\n", time_us_32(), ##__VA_ARGS__); \
    } while(0)

// Usage
DEBUG_PRINT(DEBUG_INFO, "Pattern %d started", patternId);
DEBUG_PRINT(DEBUG_ERROR, "Failed to send MIDI: %d", error);
```

### Logic Analyzer

Essential signals to monitor:
1. **MIDI TX** (GPIO8): Verify MIDI messages
2. **I2C SDA/SCL** (GPIO4/5): Check display communication
3. **Encoder pins** (GPIO14/15): Verify encoder signals
4. **LED data** (GPIO23): Check WS2812 timing

### GDB Debugging

```bash
# Connect with PicoProbe
arm-none-eabi-gdb build/genseq.elf
(gdb) target remote localhost:3333
(gdb) monitor reset init
(gdb) load
(gdb) break main
(gdb) continue
```

### Core-Specific Debugging

```bash
# Debug specific core
(gdb) break core1_main
(gdb) info threads
(gdb) thread 2  # Switch to core 1
```

## Common Error Codes

### Flash Errors

| Error | Cause | Solution |
|---|---|---|
| "No drive" | BOOTSEL not pressed | Hold BOOTSEL while connecting USB |
| "Copy failed" | Insufficient space | Delete old UF2 files first |
| "Corrupted" | Incomplete copy | Re-copy UF2 file |

### Runtime Errors

| Error | Cause | Solution |
|---|---|---|
| Hard fault | Memory access violation | Check array bounds, pointer validity |
| Stack overflow | Too much recursion/local vars | Increase stack size, reduce locals |
| Watchdog reset | Loop too long | Break long loops, use watchdog_disable() |

## Recovery Procedures

### Bricked Device

1. **Hold BOOTSEL** while connecting USB
2. **Flash fresh firmware**:
   ```bash
   # Flash a simple blink program first
   cp blink.uf2 /media/$(whoami)/RPI-RP2/
   ```
3. **If still not working**:
   - Check for physical damage
   - Try different USB cable/port
   - Test with known good Pico

### Corrupted Build

```bash
# Complete clean
rm -rf build
git clean -fdx  # Remove all untracked files
git reset --hard HEAD  # Reset to last commit

# Rebuild
mkdir build && cd build
cmake .. && ninja
```

### Lost Source Code

```bash
# Use git reflog to find lost commits
git reflog

# Restore lost commit
git checkout <commit-hash>

# Or clone fresh copy
git clone https://github.com/woeps/pico-genseq.git
```

## Getting Help

### Debug Information to Collect

1. **Build environment**:
   ```bash
   uname -a
   cmake --version
   arm-none-eabi-gcc --version
   ```

2. **Project status**:
   ```bash
   git status
   git log --oneline -5
   ```

3. **Error logs**:
   - Full build output
   - Runtime serial output
   - GDB backtrace

### Community Resources

- **GitHub Issues**: Create detailed issue with logs
- **Pico SDK Forums**: https://forums.raspberrypi.com/
- **RP2040 Datasheet**: For hardware questions
- **MIDI.org**: For MIDI specification questions

## Prevention Tips

### Development Practices

1. **Commit often**: Small, logical commits
2. **Test changes**: Verify after each modification
3. **Backup config**: Save working CMakeLists.txt
4. **Document changes**: Update README with modifications

### Hardware Protection

1. **ESD protection**: Use anti-static measures
2. **Current limiting**: Add fuses where appropriate
3. **Polarity protection**: Diode on power input
4. **Overvoltage protection**: TVS diodes on I/O

### Code Safety

1. **Bounds checking**: Prevent buffer overflows
2. **Input validation**: Check all user inputs
3. **Error handling**: Graceful failure modes
4. **Watchdog**: Enable for production code

## Summary

Most issues fall into these categories:
- **Build**: Environment setup problems
- **Runtime**: Configuration or logic errors
- **Hardware**: Wiring or component failures
- **Performance**: Timing or optimization needs

Systematic debugging with the right tools and techniques can resolve most problems quickly. Always start with the simplest explanation and work toward more complex causes.

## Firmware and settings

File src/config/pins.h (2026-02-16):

#ifndef GENSEQ_PINS_H
#define GENSEQ_PINS_H

// PIN ASSIGNMENTS & CONFIG

// BUTTONS (A-F)
#define BUTTON_A_PIN 10
#define BUTTON_B_PIN 11
#define BUTTON_C_PIN 12
#define BUTTON_D_PIN 13
#define BUTTON_E_PIN 14
#define BUTTON_F_PIN 15

#define LED_PIN 25
#define LED_MATRIX_PIN 16

// POTENTIOMETER (ADC0)
#define POT_PIN 27

// UART MIDI
#define MIDI_UART uart1    // Using UART1 for MIDI
#define MIDI_UART_PIN_TX 8 // MIDI_UART_TX
#define MIDI_UART_PIN_RX 9 // MIDI_UART_RX

#endif // GENSEQ_PINS_H

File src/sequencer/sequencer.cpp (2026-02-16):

#include "sequencer.h"
#include "midi_messages.h"
#include "pico/multicore.h"
#include "hardware/gpio.h"
#include "../common/pitch_set.h"
#include "../common/velocity_set.h"
#include "../common/gate_set.h"
#include "../common/const.h"
#include "../common/pattern.h"
#include <cstdio>

namespace sequencer {

    // Global variables for multicore communication
    static Sequencer* globalSequencer = nullptr;

    // Multicore FIFO for command passing
    static void sequencer_task(uart_inst_t* uart);

    // Sequencer implementation
    Sequencer::Sequencer(uart_inst_t* uart, uint txPin, uint rxPin) :
        uart(uart),
        bpm(120),
        playing(false),
        lastTickTime(get_absolute_time()),
        midiClockEnabled(true),
        patterns({ common::Pattern() }) {
        // Initialize UART for MIDI
        uart_init(uart, MIDI_BAUD_RATE);

        // Configure UART pins (assuming UART1 uses GPIO 4 and 5)
        gpio_set_function(txPin, GPIO_FUNC_UART);
        gpio_set_function(rxPin, GPIO_FUNC_UART);
    }

    void Sequencer::init() {
        // TODO: reset values to default
    }

    void Sequencer::update() {
        if (!playing) return;

        // Calculate time for one tick based on BPM
        uint32_t tickDurationUs = 60 * 1000 * 1000 / (bpm * PPQN);

        // Check if it's time for the next tick
        absolute_time_t currentTime = get_absolute_time();
        if (absolute_time_diff_us(lastTickTime, currentTime) >= tickDurationUs) {
            lastTickTime = currentTime;

            // Process all active patterns
            for (auto& pattern : patterns) {
                if (!pattern.isActive()) continue;

                // Get non-const references to the pattern components
                common::GateSet& gateSet = const_cast<common::GateSet&>(pattern.getGateSet());
                common::PitchSet& pitchSet = const_cast<common::PitchSet&>(pattern.getPitchSet());
                common::VelocitySet& velocitySet = const_cast<common::VelocitySet&>(pattern.getVelocitySet());

                if (pitchSet.getPitches().empty() || velocitySet.getVelocities().empty() || gateSet.getGates().empty()) continue;

                common::Flank flank = gateSet.getFlank();

                if (flank == common::RISING) {
                    sendMidiNoteOn(pattern.getMidiChannel(), pitchSet.getPitch(), velocitySet.getVelocity());
                }
                else if (flank == common::FALLING) {
                    sendMidiNoteOff(pattern.getMidiChannel(), pitchSet.getPitch());
                    pitchSet.setPosition(pitchSet.getPosition() + 1);
                    velocitySet.setPosition(velocitySet.getPosition() + 1);
                }
                int nextGatePosition = gateSet.getPosition() + 1;
                gateSet.setPosition(nextGatePosition);
            }
        }
    }

    void Sequencer::processCommand(commands::CommandMessage msg) {
        switch (msg.cmd) {
        case commands::Command::PLAY:
            play();
            break;
        case commands::Command::STOP:
            stop();
            break;
        case commands::Command::BPM_SET:
            setBPM(msg.param1);
            break;
        case commands::Command::PATTERN_ACTIVATE:
            activatePattern(msg.param1);
            break;
        case commands::Command::PATTERN_DEACTIVATE:
            deactivatePattern(msg.param1);
            break;
            // Add more command handlers as needed
        case commands::Command::PATTERN_EUCLIDEAN_SET_LENGTH:
            patternSetEuclideanLength(msg.param1, msg.param2);
        }
    }

    void Sequencer::play() {
        // Send MIDI Start message if MIDI clock is enabled
        if (midiClockEnabled) {
            sendMidiByte(midi::SystemRealTimeMessage::START);
        }
        
        // Set playing state and initialize timing
        playing = true;
        lastTickTime = get_absolute_time();
        
        // Clear pattern notes tracking to start fresh
        patternNotes.clear();
    }

    void Sequencer::stop() {
        playing = false;

        // Send note off only for active notes
        for (uint8_t channel = 0; channel < 16; channel++) {
            for (uint8_t note = 0; note < 128; note++) {
                if (activeNotes[channel][note]) {
                    sendMidiNoteOff(channel, note);
                }
            }
        }

        // set all sets in all paterns to position 0
        for (auto& pattern : patterns) {
            pattern.getGateSet().reset();
            pattern.getPitchSet().reset();
            pattern.getVelocitySet().reset();
        }
    }

    void Sequencer::setBPM(uint16_t bpm) {
        this->bpm = bpm;
    }

    void Sequencer::addPattern(const common::Pattern& pattern) {
        patterns.push_back(pattern);
    }

    void Sequencer::activatePattern(size_t index) {
        if (index < patterns.size()) {
            patterns[index].setActive(true);
        }
    }

    void Sequencer::deactivatePattern(size_t index) {
        if (index < patterns.size()) {
            patterns[index].setActive(false);
        }
    }

    void Sequencer::patternSetEuclideanLength(size_t patternIndex, size_t length) {
        printf("TODO: patternSetEuclideanLength: %d, %d\n", patternIndex, length);
        // if (patternIndex < patterns.size()) {
        //     patterns[patternIndex].setEuclideanLength(length);
        // }
    }

    void Sequencer::sendMidiNoteOn(uint8_t channel, uint8_t note, uint8_t velocity) {
        // Ensure channel and note are within valid ranges
        channel = channel & 0x0F;  // Limit to 0-15
        note = note & 0x7F;       // Limit to 0-127
        
        // Track this note as active
        activeNotes[channel][note] = true;
        
        // MIDI Note On: status byte + channel, note, velocity
        // MIDI channels are 1-based in the API but 0-based in the protocol
        uint8_t channelIndex = (channel > 0) ? (channel - 1) : 0;
        sendMidiByte(midi::ChannelVoiceMessage::NOTE_ON | (channelIndex & 0x0F));
        sendMidiByte(note & 0x7F);
        sendMidiByte(velocity & 0x7F);
    }

    void Sequencer::sendMidiNoteOff(uint8_t channel, uint8_t note) {
        // Ensure channel and note are within valid ranges
        channel = channel & 0x0F;  // Limit to 0-15
        note = note & 0x7F;       // Limit to 0-127
        
        // Mark this note as inactive
        activeNotes[channel][note] = false;
        
        // MIDI Note Off: status byte + channel, note, velocity (0)
        // MIDI channels are 1-based in the API but 0-based in the protocol
        uint8_t channelIndex = (channel > 0) ? (channel - 1) : 0;
        sendMidiByte(midi::ChannelVoiceMessage::NOTE_OFF | (channelIndex & 0x0F));
        sendMidiByte(note & 0x7F);
        sendMidiByte(0); // velocity 0
    }

    void Sequencer::sendMidiByte(uint8_t byte) {
        uart_putc_raw(uart, byte);
    }
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

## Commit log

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2025-05-09 fix incorrect note off sent by the sequencer
    [button.cpp, display.cpp]
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2026-06-18 feat(ui/hw/Potentiometer): increase change detection threshold and improve noise filtering
    [Potentiometer.cpp]
2026-08-20 docs(spec): design for USB keyboard input replacing button/pot wiring
    Replaces GPIO buttons and the ADC potentiometer with a USB HID keyboard on
    the Pico's native USB port. Key decisions: native tinyusb_host transport,
    KeyId enum carrying HID usage codes with a combo() packing helper, KEY_HELD
    as auto-repeat, F1-F12/space reserved as global bindings handled in reduce()
    ahead of view delegation, and a host-side test target for the report-diff
    and repeat-timing logic.
    Claude-Session: https://claude.ai/code/session_01DuTSiTZe27P3QAbSG1uWCy
2026-08-20 docs(plan): implementation plan for USB keyboard input
    Five tasks: host test harness + key types, event-vocabulary swap with the
    old input wiring removed, reducer global bindings, KeyboardDecoder, and
    TinyUSB host wiring. Each task ends buildable and independently testable.
    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
2026-08-20 refactor(ui): replace button/pot events with key events
    Deletes Button and Potentiometer, swaps EventType to KEY_PRESSED/
    KEY_RELEASED/KEY_HELD carrying KeyId plus modifiers, rewrites InitView
    to an up/down sweep with shift for coarse steps, sizes the view arrays
    by ViewId::COUNT, and clamps value 0-99 inside setValue.
    The firmware has no input source until the USB keyboard is wired in.
    [Button.cpp, Potentiometer.cpp]
2026-08-20 fix(ui): zero-init view registry and drop unused handleEvent param
    Review findings on the button/pot->key-event swap:
    - UIController::views was default-initialized with indeterminate
    pointers and then overwrote StateManager's nulled array during
    initialize(), silently defeating the null-pointer guard that sizing
    by ViewId::COUNT depends on as the view set grows. Zero-init with {}.
    - IView::handleEvent's unused event parameter triggered -Wunused-parameter
    in every TU that now reaches IView.h via the host test build. Drop the
    parameter name; state stays named since it is returned.
2026-08-20 feat(ui/hw): add KeyboardDecoder with HID report diffing and auto-repeat
    Pure logic with an injected clock: set-based report diffing that tolerates
    slot reshuffles, ErrorRollOver reports discarded whole, right-hand modifiers
    folded onto left, last-pressed-key auto-repeat at 400ms/30ms scheduled
    forward from now, wrap-safe deadlines, and disconnect releasing everything
    still down.
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2026-08-20 fix(ui/hw): trace key events and surface TinyUSB arming failures
    The re-arm call to tuh_hid_receive_report() in tuh_hid_report_received_cb
    is the only thing keeping HID reports flowing. It fails via TU_VERIFY,
    which does not log even at CFG_TUSB_DEBUG=1, so a single dropped return
    value left the keyboard permanently dead with total silence on the
    UART - indistinguishable from a wiring or power fault. Check and log
    that return value, plus the two other dropped TinyUSB return values
    (tuh_init, and the initial arm in tuh_hid_mount_cb).
    Wire up ui::toName(KeyId), which previously had no callers outside
    tests, as a trace line in UsbKeyboard's decoder sink. Only KEY_PRESSED
    and KEY_RELEASED are t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
2026-08-20 build: add CONFIGURE_DEPENDS to source globs
    file(GLOB_RECURSE ...) without CONFIGURE_DEPENDS freezes the file list
    at configure time. This bit the USB-keyboard branch twice: deleting
    Button.cpp/Potentiometer.cpp broke the build with a stale ninja rule,
    and adding KeyboardDecoder.cpp/UsbKeyboard.cpp would have been silently
    omitted from a green build without a manual reconfigure. Adding
    CONFIGURE_DEPENDS to all four globs (sequencer, common, commands, UI)
    makes CMake re-glob whenever the build is invoked, removing the need
    for manual reconfigures. cmake_minimum_required is already 3.13;
    CONFIGURE_DEPENDS only needs 3.12, so no version bump is required.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
2026-08-20 docs: add USB keyboard bring-up and verification guide
    The USB HID keyboard input path is the one part of this codebase no
    automated test can exercise - enumeration, power delivery, hub
    traversal, and disconnect/reconnect state clearing all require real
    hardware. Add a standalone, tracked guide covering: VBUS power wiring
    (the most common bring-up failure), the correct trace UART (uart0,
    GPIO 0, 115200 - not the uart1/GPIO 8 MIDI link), pre-flight sanity
    checks, the 10-point functional checklist, and troubleshooting for
    boot-subclass keyboards, composite HID devices, hub paths, and
    Debug-vs-Release diagnostic availability. Linked from the sidebar
    alongside the existing Build & Flash and MIDI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
2026-08-23 fix overrun in sequencer
    [sequencer.cpp]
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2026-08-28 fix: prevent MIDI clock drift by advancing lastTickTime by tickDurationUs
    Instead of setting lastTickTime = currentTime (which anchors the next
    tick deadline to the actual detection time, accumulating drift), advance
    it by exactly tickDurationUs. This keeps the tick phase locked regardless
    of late detection in update().
    [sequencer.cpp]
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2026-08-29 Add durable settings persistence with flash-backed save/restore
    - Introduce persistence layer (FlashStore, PersistenceManager, SaveRecord,
    PersistableConfig) storing config in a reserved flash region with CRC
    - Wire Ctrl+S save flow: reducer sets saveRequested, core0 UI loop drains it,
    performs the synchronous flash write, and shows a save-feedback banner
    - Restore saved config at boot and replay it into core1 via the sync-command
    path; show NOT_LOADED banner on load failure
    - Refactor Sequencer to depend on IMidiOutput; add UartMidiOutput and
    core_pause/sequencer_task helpers
    - Add host-compilable test suite (property + example tests) with pico stubs
    - Ignore nested build directorie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
    [sequencer.cpp]
2026-10-17 docs(perf): capture hardware timing baseline (Milestone 2 task 1.4)
    Measure the current implementation on RP2040 with a BitScope BS05U logic
    analyzer via the firmware GPIO trace pins, separating logical scheduling
    jitter from MIDI wire skew (Req 9.2, 9.3, 11.6, 11.7).
    Findings:
    - Logical scheduling jitter below the analyzer floor at 40/120/255 BPM and
    under 8-pattern load; tick service ~5.5us, MIDI dispatch <25ns.
    - MIDI wire skew is 320us/byte (31250 baud confirmed); coincident notes
    serialize into a ~2.2ms burst.
    - Ctrl+S save blocks ~33ms with MIDI output fully stalled -- ~32x over the
    Req 9.3 1ms budget. This is the defect Milestone 2 targets.
    Adds docs/development/baseline/ (wri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
2026-10-17 perf-safe-foundation: wave 1 (tasks 2.1, 2.2, 3.1)
    Milestone 2 foundation types, all SDK-free and host-tested:
    - 2.1 Canonical MIDI channel (Req 5.1, 5.9): common/MidiChannel.h gives one
    protocol-channel (0..15) representation with lossless 1..16 boundary
    conversion and removes the channel 0/1 alias. Sequencer emits via the
    canonical channel and indexes activeNotes by protocol channel, fixing the
    stop()/activeNotes indexing mismatch. Pattern gains getCanonicalChannel().
    - 2.2 Stable PatternId (Req 5.1, 6.9, 7.8): common/PatternId.h adds a
    fixed-capacity, allocation-free allocator minting (slot, generation)
    identities. Removal/reorder of one pattern never retargets another; a re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
2026-10-17 perf-safe-foundation: wave 2 (tasks 2.3, 3.2)
    - 2.3 NoteLifecycle (Req 5.1-5.5, 5.8): sequencer/NoteLifecycle.h, one
    fixed-capacity service for all note emission. At most one OwnedNote per
    monophonic pattern (recorded by canonical channel+note at onset); an
    aggregate refcount per (channel,note) emits every retrigger and defers the
    final Note Off until the last owner releases. releasePattern/releaseAll/panic
    leave zero per-pattern and aggregate ownership; stale-generation releases are
    ignored.
    - 3.2 TransportTimeline (Req 1.1-1.5): sequencer/TransportTimeline.h owns BPM,
    PPQN, meter, logical tick index and intended timestamps, derives beat/bar
    indices, and preserves phase acr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
2026-10-17 perf-safe-foundation: wave 3 (tasks 2.4, 2.5, 3.3, 4.1)
    Wire the wave-1/2 services into the real Sequencer hot path:
    - 2.4 Route gate edges + Stop through NoteLifecycle (Req 5.2, 5.8, 5.10):
    rising edge records ownership by canonical channel + current pitch; falling
    edge releases the RECORDED onset via PatternId (not the edited pitch); Stop
    releases all ownership; repeated Play is a deterministic no-op (no second
    Start, ownership intact).
    - 2.5 Note-safe destructive ops (Req 5.6, 5.7): deactivate (mute) and remove
    release the pattern's owned note at the boundary before deactivating/
    destroying runtime state; set replacement lets the current note finish via
    its recorded lifecy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
2026-10-17 perf-safe-foundation: wave 4 (tasks 2.6, 3.4, 4.2, 5.1)
    - 4.2 MidiEventQueue.h: fixed-capacity ring with deterministic coincident
    ordering (timestamp, class priority, PatternId, enqueue seq), real-time
    priority, and reserved safety capacity (ordinary events refused into the
    reserve; a full-queue safety event reports DirectRequired for a bounded
    direct path). High-water metric exposed.
    - 5.1 Scheduler.h + sequencer.cpp: Scheduler::service(now) front end — safety
    work first, every tick gets its intended timestamp, bounded per-service tick
    budget (default 8) with surplus-overdue reporting; update() refactored to
    drive sequencing through it.
    - 2.6 property3_note_lifecycle_model.c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
2026-10-17 perf-safe-foundation: wave 5 (tasks 4.3, 5.2, 5.3, 6.1, 6.2)
    - 5.3 PerformanceFault.h: latched fail-closed state machine (cause + latched
    measurement, idempotent enter, explicit-Play acknowledge). Wired into the
    Sequencer: enterTimingFault releases all notes, emits Stop when enabled,
    stops transport, preserves Working State; play() acknowledges a latch and
    restarts from defined positions (Req 10.1-10.7).
    - 5.2 Scheduler.h: bounded under-one-beat reconciliation — a tick overdue by
    >= one period is routed through a reconcile callback (phase advance + crossed
    Note Off only, no obsolete Note On, no obsolete Clock); only the authoritative
    tick runs normally. serviceTick(reconcileO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
2026-10-17 perf-safe-foundation: wave 6 (tasks 4.4, 5.4, 6.3, 6.4, 7.1)
    - 7.1 TimingPolicy.h: Immediate/Next Beat/Next Bar effective-tick resolution
    against the TransportTimeline; on-boundary -> next-boundary convention; isDue.
    - 6.3 CommandInbox.h: added coalescing key + barrier flag to InboxCommand;
    tryPushCoalescing (latest-wins by (target,property), never across a barrier),
    popPriority (safety ops ahead of ordinary edits), documented never-block
    saturation (full -> kInvalidSequence).
    - 6.4 PatternSnapshot.h: fixed-capacity, allocation-free container (packed gate
    bitset + pitch/velocity arrays, protocol-cap clamping, clear-and-reuse,
    documented footprint) for the heap-free core1 receive-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
2026-10-17 perf-safe-foundation: wave 8 host-testable (tasks 7.4, 8.2, 11.1)
    - 7.4 PatternSnapshotApply.h: applyPatternSnapshot swaps the complete gate/
    pitch/velocity material in one step (no partial state visible to the tick
    path); the sounding note, owned by NoteLifecycle by recorded identity, is
    preserved and the new material drives the next onset (Req 5.7, 6.8, 7.1).
    - 8.2 persistence/SaveService.h: bounded begin/pump/terminal state machine over
    IFlashStore so the UI loop is never monopolized; immutable snapshot write,
    no overlapping saves, distinct SUCCESS/FAIL outcome, UI/input service-gap
    metric (Req 8.5-8.9).
    - 11.1 UIState.h: distinct latched timingFaultLatched + timingFaultCause,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
2026-10-17 perf-safe-foundation: wave 9 host-testable (tasks 7.5, 8.3, 10.1, 11.2, 11.3, 12.1)
    - 10.1 persistence/RecordStore.h: backend-neutral A/B transactional record store
    over IFlashStore — two slots, monotonic generation, commit to the alternate
    slot, newest-valid-committed selection; a failed/interrupted commit preserves
    the previous record (Req 9.1, defines the 9.6/9.7 shape for 10.2).
    - 11.2 ui/state/FaultIndication.h: persistent fault matrix-color policy, distinct
    from and taking precedence over the save/load banner, no auto-dismiss
    (Req 10.4/10.5); compile-time distinct-color assertion.
    - 11.3 FaultIndication.h: acknowledgeFaultOnPlay clears the latch on explicit
    Play only (Req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
2026-10-18 docs(baseline): task 9.2 — internal flash save under worst-case live load
    Benchmark the Ctrl+S save on the hardened agents-branch firmware (9f992fb)
    under 10-pattern live load, answering what the task-1.4 baseline could not:
    - 120 BPM: 34.94 ms freeze; 255 BPM: 37.03 ms freeze (15.8% of a beat).
    Zero ticks + zero MIDI bits for the whole interior — both cores park.
    - RAM-resident path audit: hardened pause prevents an XIP-down crash but does
    NOT keep sequencing alive during the write.
    - Coincident-burst note-safety: a sounding note's off is deferred ~36.67 ms,
    then 324 queued MIDI edges flood out well-formed over 5.5 ms at the 31250-baud
    floor. No dropped/corrupted bytes — defe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
2026-10-18 feat(seq): cut core1 command receive over to allocation-free PatternSnapshot (task 6.4)
    The core1 receive loop decoded each multiword pattern-set command into
    std::vector members of CommandMessage via .assign() — steady-state heap
    allocation on the timing-critical core, forbidden by Req 7.9.
    Add an allocation-free sibling path and cut the firmware over to it:
    - commands::receiveCommandInto(PatternSnapshot&): identical FIFO decode, but
    gate/pitch/velocity payloads land in a caller-owned, reused fixed-capacity
    PatternSnapshot instead of heap vectors.
    - Sequencer::processCommand(msg, snapshot): applies the three set commands from
    the snapshot buffers; validates set commands against the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
2026-10-18 feat(persistence): add MB85RS2MTA FRAM driver behind IFlashStore (task 9.3 prep)
    Writes the external SPI FRAM backend before the chip is in hand so 9.3 becomes a
    pure bench measurement, not driver debugging. The MB85RS2MTA is 2 Mbit/256 KB
    with a 3-byte (24-bit) address; FRAM has no erase and is byte-writable in place,
    so a save is plain SPI traffic that never disables XIP — the fix for the ~37 ms
    both-core freeze the 9.2 captures measured.
    - Mb85rsFram (SDK-free): implements IFlashStore over an abstract IFramSpi with
    explicit CS framing. eraseAndProgram = WREN -> WRITE@0 -> read-back verify;
    3-byte address emitted MSB-first; readDeviceId for bring-up.
    - Mb85rsFramSpi (firmware-only h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
2026-10-18 fix(seq): implement Sequencer::init() as a defined-baseline reset
    init() was an empty '// TODO: reset values to default' stub. Implement it as an
    idempotent runtime reset to the power-on baseline: acknowledge any latched
    Timing Fault, stop playback, release all note ownership, restore default tempo
    and MIDI-clock-enabled, and reset every pattern's gate/pitch/velocity runtime
    position. Working State (the pattern slots and their identities) is preserved
    with no vector churn, so the reset is allocation-safe.
    New test_init_resets_to_baseline in example_sequencer_integration: init()
    releases a held note, leaves playback stopped (tick emits nothing), is
    idempotent, and Play still works afterward.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
2026-10-18 docs(todo): verified FRAM wiring, pin table + ASCII pinout for 9.3
    Confirmed GP10-13 (SPI1) are free: the LCD Display is not instantiated in
    the live build and pins.h defines no I2C pins, so there is no clash to
    resolve. Expanded the wiring section with physical Pico pin numbers,
    WP/HOLD split out, the 8 MHz start-clock note, an ASCII pinout diagram,
    and the RDID bring-up/fault-diagnosis sequence.
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2026-10-19 fix(10.3): stop the live FRAM save from crashing both cores
    Two concurrency/resource bugs the live save path hit on hardware, each
    found by halting the hung target over SWD and reading the backtrace.
    1. core1 double-faulted (heap corruption). RecordStore::writeSlotRegion
    allocated an 8 KB whole-region std::vector on core0 every save, running
    concurrently with core1 on the shared allocator with no malloc mutex (the
    dropped flash path used to park core1 for the write). Fix: add
    IFlashStore::programAt(offset,data,len) — Mb85rsFram implements it
    allocation-free, writing ONLY the target A/B slot in place (FRAM is
    byte-writable, no erase, so the other slot is physically preser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
2026-10-19 Add host-control channel + live-trace build for autonomous bench testing
    HostControl (GENSEQ_HOST_CONTROL, off by default) reads newline-framed
    "H:" commands from stdin (UART0/picoprobe bridge) and synthesizes the
    same ui::events::Event values a keypress would, dispatched through the
    identical StateManager::dispatch() seam as the USB keyboard -- no new
    path into the state machine. Commands: ping, save (=Ctrl+S), play
    (=SPACE), view, up/down/left/right [coarse], bpm, pattern, dump, and
    reset (watchdog self-reboot = autonomous power-cycle).
    Enables hands-off 12.3/12.4 verification: set a known config, trigger a
    real FRAM save at a controlled instant, self-reset, and read restored
    state back -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
2026-10-19 test(12.3): autonomous FRAM boot-load round-trip harness
    Host-side pyserial script driving the HostControl channel (f699ec8) to verify
    the external-FRAM persistence path end-to-end with no keypress and no human
    power-cycle: H:bpm N -> H:dump -> H:save -> H:reset (watchdog self-reboot) ->
    reconnect -> H:dump -> assert bpm/patternCount/activePatterns survived.
    Verified on hardware across three successive cycles (bpm 177/222/88), each a
    distinct value surviving save + reboot -> the A/B transactional commit,
    generation selection, and boot-load all work on real silicon. view correctly
    resets (transient); timingFault stays 0 across the save.
    test/bench/README.md documents the build+flash+run pro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
2026-10-19 docs(12.x): reconcile task status with hardware-verified evidence
    Annotate 12.3/12.4/12.5 with honest partial status rather than marking them
    complete. Verified on the FRAM backend via the autonomous bench rig:
    - live-save transparency at 255 BPM (ticks hold 9.8 ms cadence through a
    ~10 ms real save; a MIDI dispatch lands in-window; timingFault never latches),
    - boot-load round-trip (bpm/patternCount/activePatterns survive save+reboot) 3x.
    OUTSTANDING for a full Milestone 2 sign-off (12.5 gates on these): BPM 40/120
    sweep, meter variants, edit storms, overload, explicit jitter + UI/save-gap
    number capture (12.3); the full mute/remove/edit/Stop/fault+overlap event
    matrix, long-duration pla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
2026-10-19 feat(12.3/12.4): literal timing + stuck-note metrics over host-control
    Replace the proxy evidence with direct measurements exposed in H:dump:
    - D:lastSaveUs — wall-clock duration of the live RecordStore::commit, measured
    in UIController. MEASURED 10.5-10.6 ms across 8 saves (<= 100 ms save-gap
    limit). PASS, literally.
    - D:soundingNotes — NoteLifecycle sounding-note count, published cross-core via
    g_soundingNotes (sequencer_telemetry.h). MEASURED 2 under load -> 0 after
    Stop. PASS (no stuck note), literally. Publish moved ABOVE update()'s
    not-playing early-return so it reflects Stop's releaseAll() instead of
    freezing at the last played value.
    - D:maxUiGapUs — longest UI-loo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
2026-10-19 docs: re-open Milestone 2 — literal UI-gap metric fails the <=50 ms limit
    The now-literal metrics (commit 14af66e) confirmed save-time gap (10.6 ms) and
    stuck-notes (0 after Stop) pass, but also surfaced a real, recurring ~501 ms
    core0 UI-loop stall (maxUiGapUs) in idle playback — far over the <=50 ms limit.
    Not the save (clean 10.6 ms) and invisible to the core1 timingFault proxy. Task
    12.3 FAILS one gate; per the spec rule Milestone 2 is not complete until it
    passes. Re-opened 12.3/12.5/parent 12; 12.4 stays done (stuck-note now literal).
2026-10-19 diag(12.3): pin the ~501 ms UI stall to tuh_task() event processing
    Per-section H:dump timing (maxKbUs/lastKbUs/lastHcUs) isolates the stall:
    maxKbUs=500.1 ms while lastKbUs is normally 3 us — a PERIODIC 500 ms spike
    inside keyboard->update(), which is tuh_task()+decoder.tick(). decoder.tick is
    pure logic, so the stall is TinyUSB's tuh_task().
    Ruled out: osal_queue_receive is non-blocking on the pico OSAL (ignores the
    UINT32_MAX timeout, 'always behave as msec=0'), so tuh_task does NOT block
    waiting for events — the 500 ms is spent PROCESSING an event (a HID/hub/control
    transfer handler busy-waiting), inside the TinyUSB host stack. Narrowing which
    event needs stepping into SDK internals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
2026-10-19 docs(12.3): root-cause the UI stall — TinyUSB 500ms enumeration delay
    The ~500 ms UI-loop stall is pinned (SWD + per-section timing): it is entirely
    inside tuh_task()'s blocking enumeration delay ENUM_RESET_DELAY_MS(50) +
    ENUM_DEBOUNCING_DELAY_MS(450) = 500 ms, recurring (~2 s) because the host keeps
    re-attempting enumeration with no successful mount on the UART — a device/hub
    that never enumerates cleanly, or a bouncing/absent connection on the
    picoprobe bench rig (CFG_TUH_HUB=1). tuh_task runs inline on the core0 UI loop.
    Fix is either driving tuh_task off the UI-critical path or confirming a stable
    real keyboard on the native port; needs a bench USB check. Not a save-path
    issue.
2026-10-20 docs(12.3): confirm UI-stall device — Logitech composite USB receiver
    Fresh enumeration: addr1 = 3 HID interfaces (idx0 keyboard mounted+works,
    idx1/idx2 mouse/Unifying vendor HID ignored). Keyboard enumerates once and
    functions; the recurring ~500 ms tuh_task stall is periodic receiver activity
    on the unserviced idx1/idx2 endpoints / wireless keepalive, re-entering the
    blocking enum/debounce path inline on the core0 UI loop. Not wiring/VBUS/UART.
    Device-independent fix: decouple tuh_task from the UI-critical path.
2026-10-20 fix(12.3): keep UI serviced during TinyUSB host delays (501ms -> 26ms)
    Root cause: a wireless Logitech receiver re-triggers TinyUSB host enumeration,
    whose blocking ENUM_DEBOUNCING_DELAY_MS(450)+ENUM_RESET_DELAY_MS(50)=500 ms
    runs inline from tuh_task() on the core0 UI loop (confirmed: the override sees
    tusbDelayMaxMs=450), blanking the UI past the Req 8.7 <=50 ms budget.
    Fix: override TinyUSB's weak tusb_time_delay_ms_api to pump a render-only UI
    callback (UsbHostDelayPump.cpp + UiPump.h) while it waits — the full delay still
    elapses (enumeration timing preserved) but the UI keeps rendering. UIController
    registers a reentrancy-safe render-only pump (pumpRender: LED+active view+banner,
    NO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
2026-10-20 docs(12.5): close Milestone 2 — UI-gap gate fixed, all gates pass
    The last failing gate (12.3 UI-gap, ~501 ms) is fixed (commit 412557b: UI render
    pump during the TinyUSB host delay, 501 ms -> 26 ms, under the 50 ms limit). All
    12.x gates now pass; marked 12.3/12.5/parent 12 complete and restored the
    ROADMAP Milestone 2 status to Complete (v1 backend = external FRAM).
2026-10-20 chore(12.3): trim UI-stall root-cause diagnostics
    Remove the temporary per-section timing (maxKbUs/lastKbUs/lastHcUs) and the
    tusbDelayCalls/tusbDelayMaxMs counters added only to pin the UI stall. The
    H:dump now carries just the real acceptance metrics: lastSaveUs, maxUiGapUs,
    soundingNotes (+ the normal state fields). The UI-pump fix itself is unchanged;
    UI gap re-verified at 18 ms (<= 50 ms). Default firmware + host 33/33 clean.
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
